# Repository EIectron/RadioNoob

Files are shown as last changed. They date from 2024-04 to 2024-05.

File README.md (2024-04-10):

<div align="center">
  <b>
   <h1>
      Radionoob AT9
   </h1>
   <h6>
     V1
   </h6>
  </b>

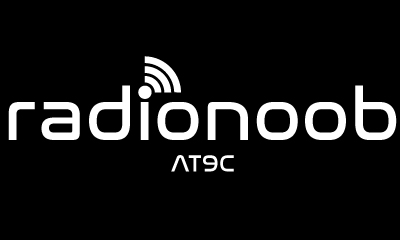
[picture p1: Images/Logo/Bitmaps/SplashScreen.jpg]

</div>

## What is this project?
My aim in this project, which I started as a hobby using the box of my broken Radiolink AT9 radio transmitter, was to control the drone in a simple way using the [ExpressLRS](https://github.com/ExpressLRS) module. In addition, I designed equipment that will contribute to my personal development. 
[For hardware information](Hardware.md);

I have personally reached the end of this project that I created with these goals. Even though it is not completely professional, I have created a remote control that will do the job. I made both the hardware and software files open source to guide beginners who want to make their own remote control. Who knows, maybe someone will make the code I wrote more meaningful :)

### This short demonstration [Youtube](https://youtu.be/xDq1djXwKw4)

## Known bugs;
- [ ] DAC player has been disabled because it falling CRSF communication.
- [ ] I cannot refresh much on the main screen, the delay is too much.
- [ ] There is an error in the screen refresh when moving to the upper menu on the ExpressLRS settings page.
- [ ] I never looked at the battery reading section.

### Goals for advanced level?
- [ ] The software must be converted to task structure with FreeRTOS.
- [ ] When I connect the USB, it should offer the option "charging or SIMULATOR" and continue according to my choice. An animation of the battery charging, maybe a current graph, and in the simulator, it goes into HID mode and communicates with the computer.

### Sources that inspired me while doing this project:
- [@danxdz](https://www.github.com/danxdz) https://github.com/danxdz/simpleTx_esp32/tree/master
- [@kkbin505](https://www.github.com/kkbin505) https://github.com/kkbin505/Arduino-Transmitter-for-ELRS
- [@DeviationTX](https://www.github.com/DeviationTX) https://github.com/DeviationTX/deviation
- [@r-u-t-r-A](https://www.github.com/r-u-t-r-A) https://github.com/r-u-t-r-A/STM32-ELRS-Handset/tree/4b6b6f61b5f094afb384d3d6aad8195b43e8a78a
- [@opentx](https://www.github.com/opentx) https://github.com/opentx/opentx/tree/2.3
- [@crsf-wg](https://www.github.com/crsf-wg) https://github.com/crsf-wg/crsf
* https://caolan.uk/notes/2020-10-14_bramley_driving_a_sharp_memory_display_from_rust/

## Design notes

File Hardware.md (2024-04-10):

<div align="center">
  <b>
   <h1>
      Radionoob AT9
   </h1>
   <h6>
     V1
   </h6>
  </b>

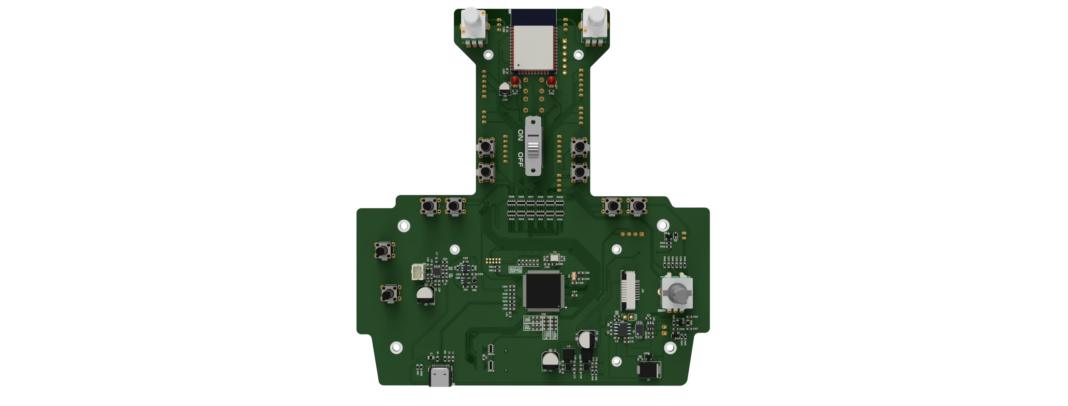
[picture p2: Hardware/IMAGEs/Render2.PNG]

</div>

#### Hardware Features;
* Nuvoton **M483KIDAE** MCU Arm® Cortex®-M4F processor 192 MHz
* 1S LiPo or 18650 Li-Ion Battery USB charge and protection
* 2.4GHz ELRS Transmitter W/ S.PORT
* PAM8304ASR DAC1 Audio sound output
* USB2.0 Full Speed communication
* SD Card
* 2.7" Sharp Memory Display
* 8x Trim button
* 8x Analog Input
* 5x One Way Button (SWA, SWB, SWD, SWF, SWH)
* 3x Two Way Button (SWCup, SWCdwn, SWEup, SWEdwn, SWGup, SWGdwn)
* PPM Data in & PPM Data out
* PWM vibration motor
* 12-bit 5 MSPS SAR ADC

### Check [Schematic](./Hardware/Schematic/RadioNoob.pdf)

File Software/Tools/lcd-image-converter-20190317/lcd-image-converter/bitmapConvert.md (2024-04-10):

## How to convert pictures for monochrome sharp memory display?

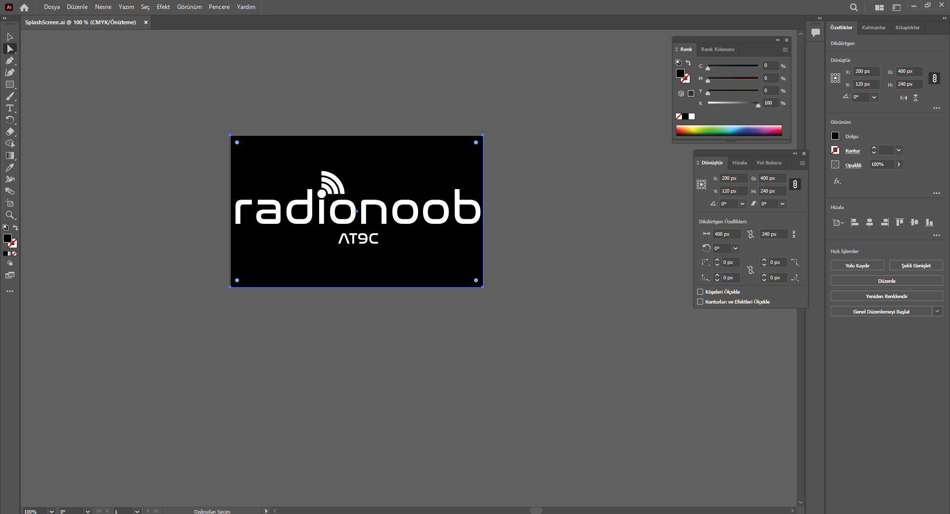
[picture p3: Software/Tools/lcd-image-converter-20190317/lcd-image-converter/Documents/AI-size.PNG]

1.) The dimensions of your work in the visual design program should not be larger than 400x240 pixels.

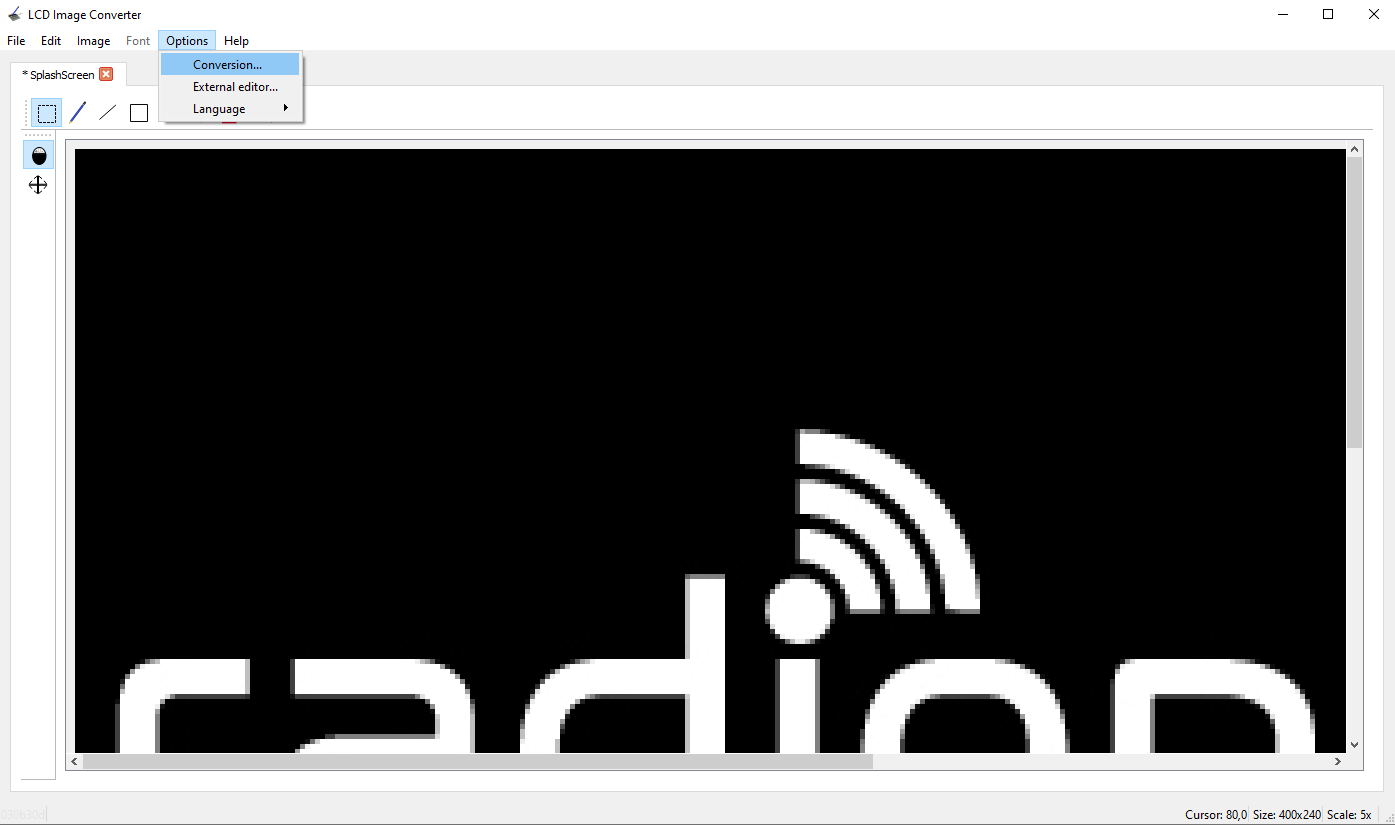
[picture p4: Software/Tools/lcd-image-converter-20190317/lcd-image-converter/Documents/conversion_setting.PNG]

2.) And open the image .jpeg or .png doesn't matter. Enter the conversions setting from the options tab

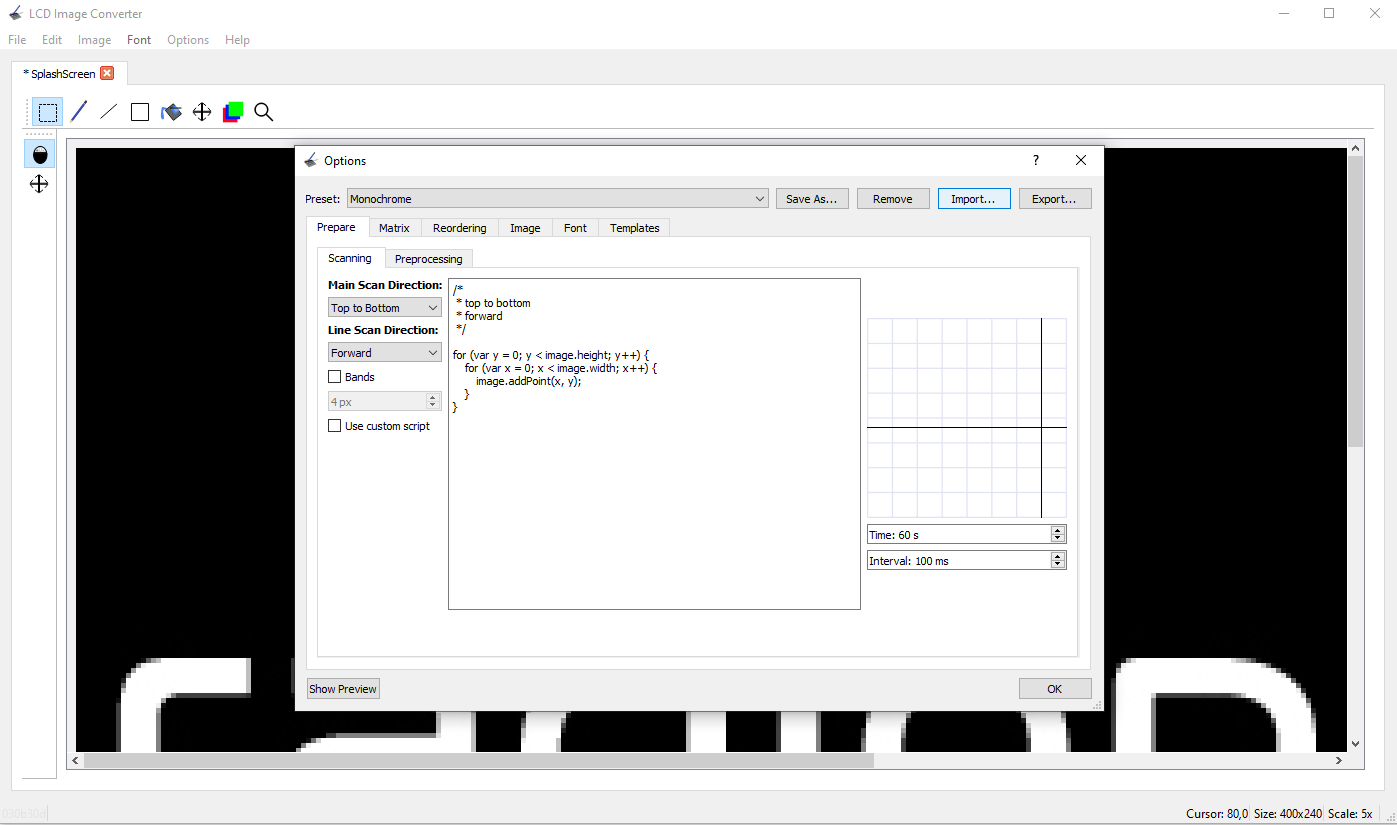
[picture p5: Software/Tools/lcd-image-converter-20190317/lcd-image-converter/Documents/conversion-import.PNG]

3. Import to Monochrome.xml file.

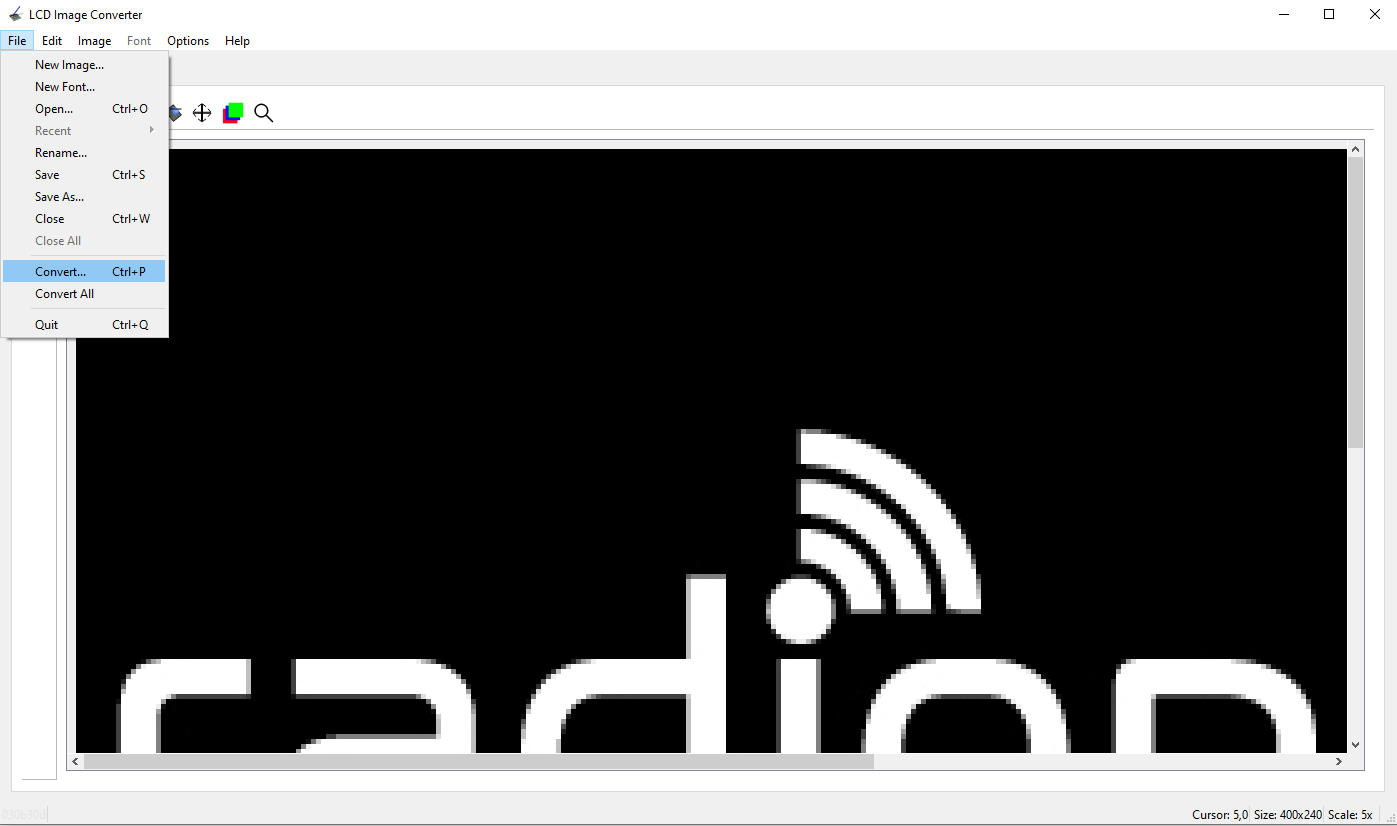
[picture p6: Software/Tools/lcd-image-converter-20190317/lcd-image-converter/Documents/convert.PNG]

4. Convert image

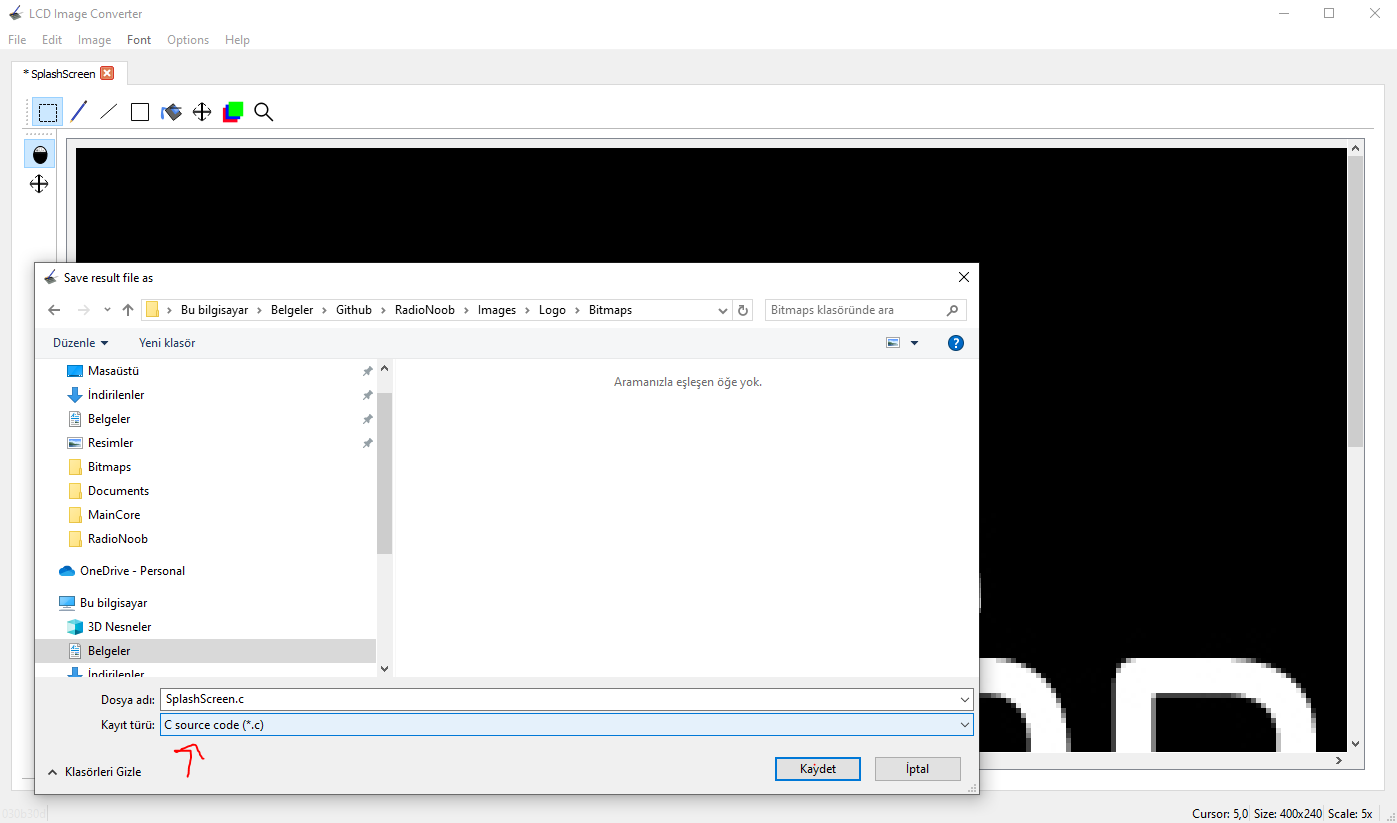
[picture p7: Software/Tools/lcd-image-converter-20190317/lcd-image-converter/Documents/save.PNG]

5. File settings must be `C source code(*.c)`

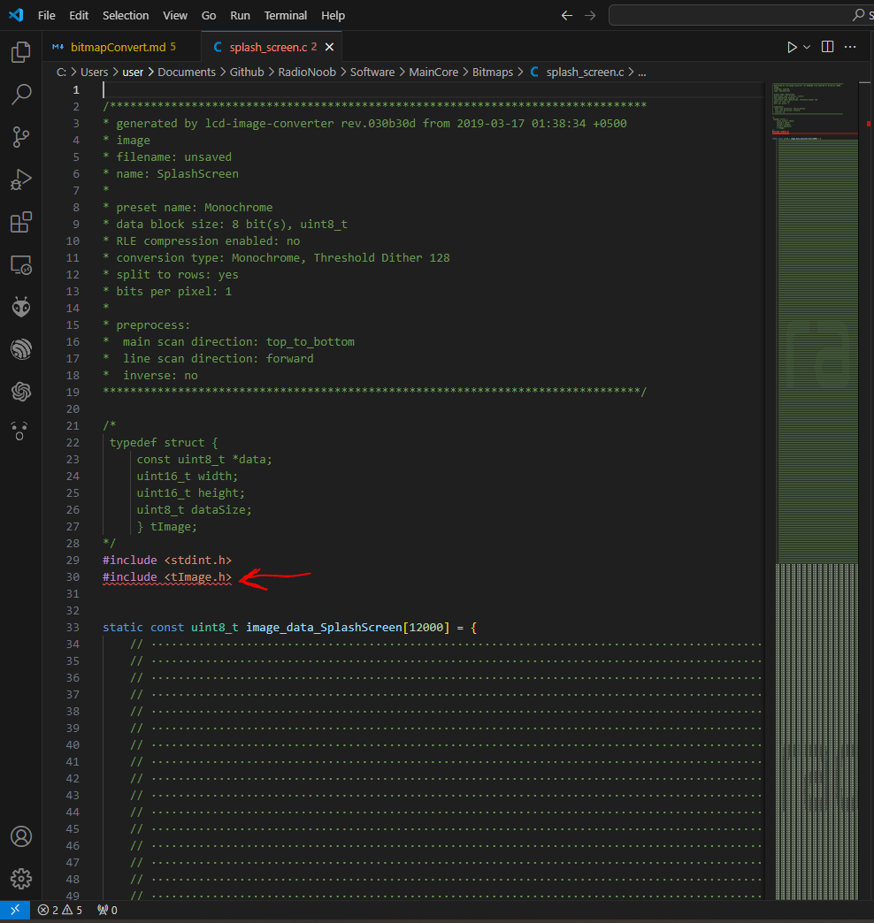
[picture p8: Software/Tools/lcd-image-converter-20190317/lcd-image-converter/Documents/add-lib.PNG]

6. After open the converted file and add to up side `#include <tImage.h>`

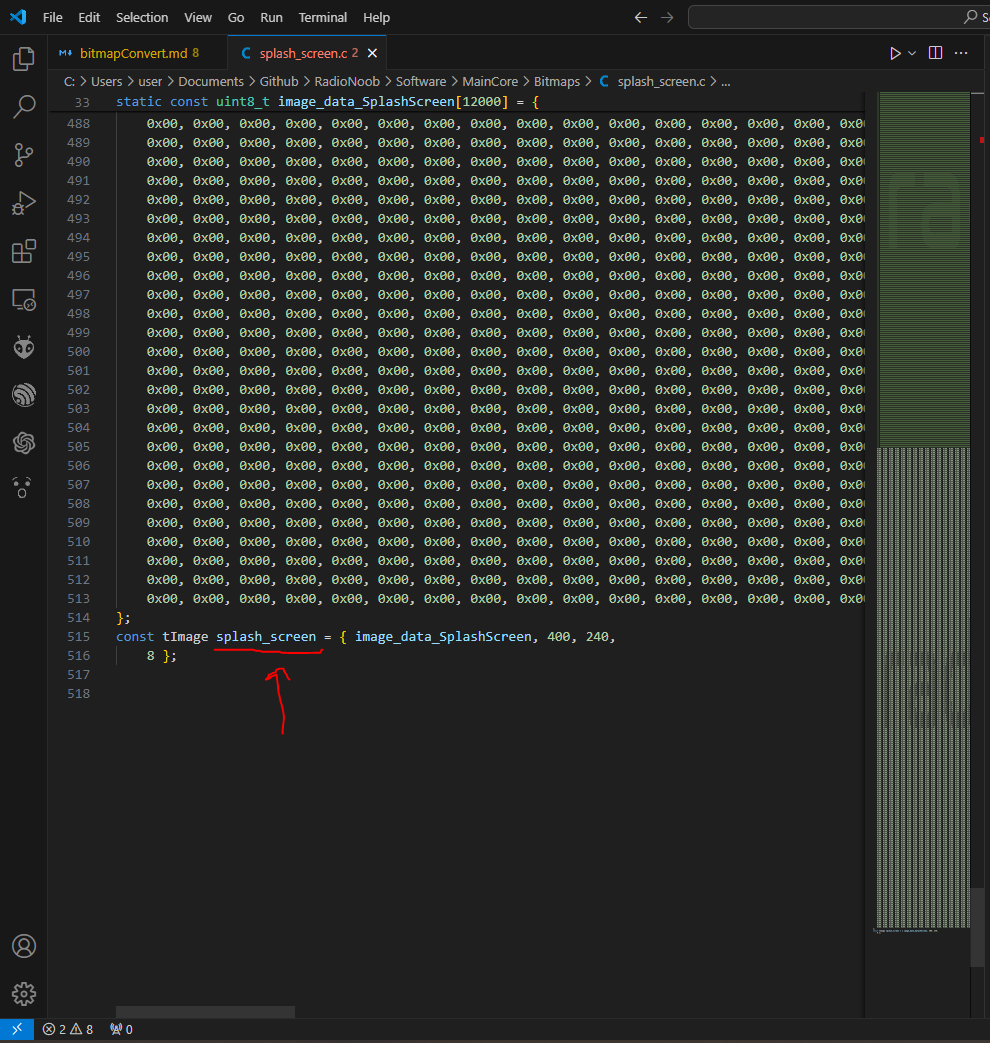
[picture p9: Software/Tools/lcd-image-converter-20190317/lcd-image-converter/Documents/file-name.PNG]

7. This is c file name

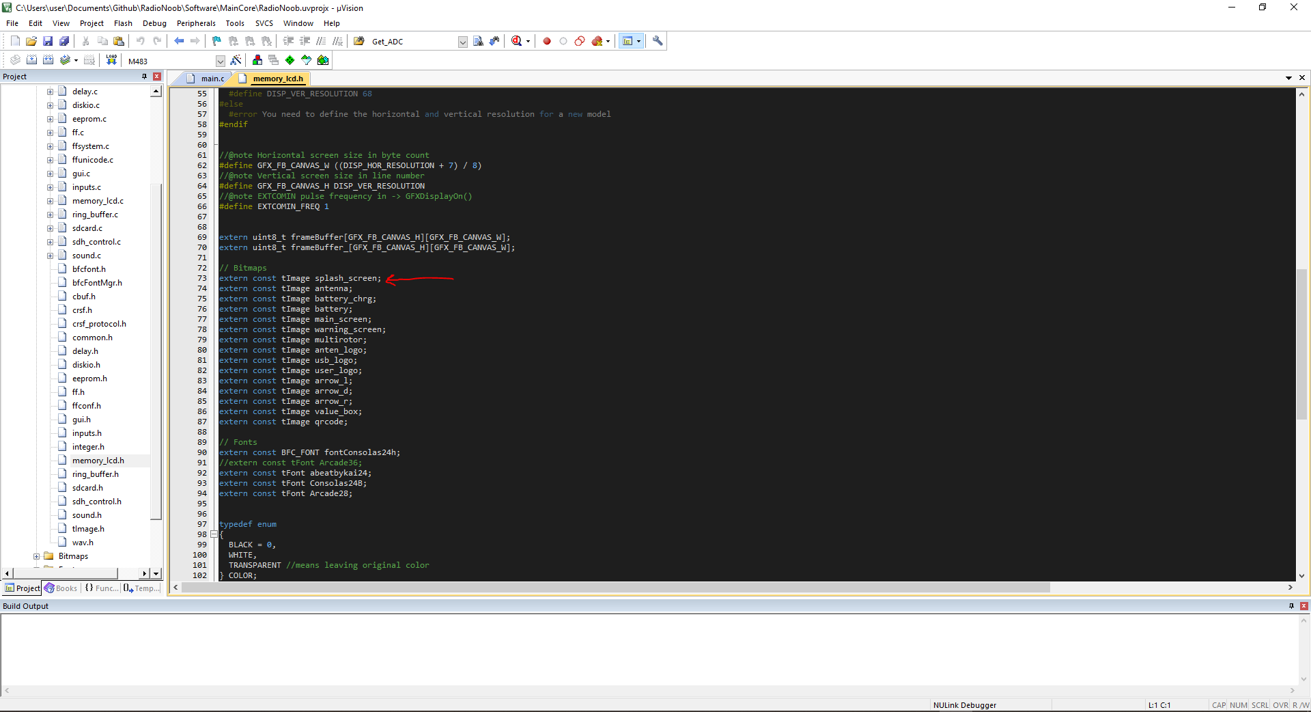
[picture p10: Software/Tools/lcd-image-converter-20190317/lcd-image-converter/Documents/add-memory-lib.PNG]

8. It is ready for use after adding it to the memory_lcd.h file in the Library folder as shown in the figure.

ex. 
``` C
GFXDisplayPutImage(0, 0, &splash_screen, false);
```

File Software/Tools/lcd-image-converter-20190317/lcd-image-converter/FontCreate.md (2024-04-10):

## How to convert pictures for monochrome sharp memory display?

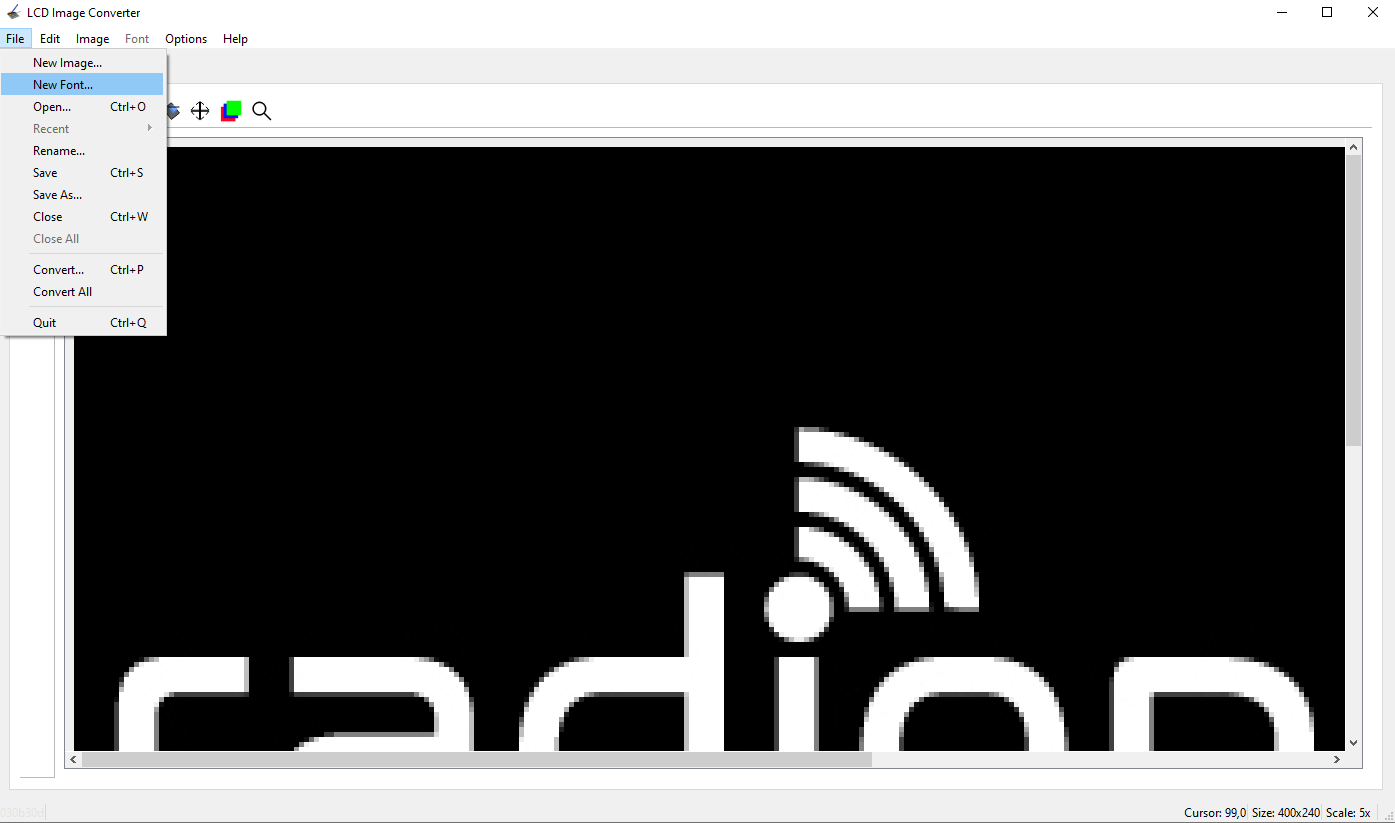
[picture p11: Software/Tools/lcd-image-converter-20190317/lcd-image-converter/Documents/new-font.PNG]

1. First, open a word file and check whether the font you want to create is installed on your computer. The font sizes of the font you choose are important. Because you need to know this in order to be standard when giving a name. For example, the naming for an arial font of size 14 will be "Arial14". If I name it "Arial22", if there is no such size, I will have to create it again. If all checks ok you click to File -> New Font and Write to your selected Font Name.

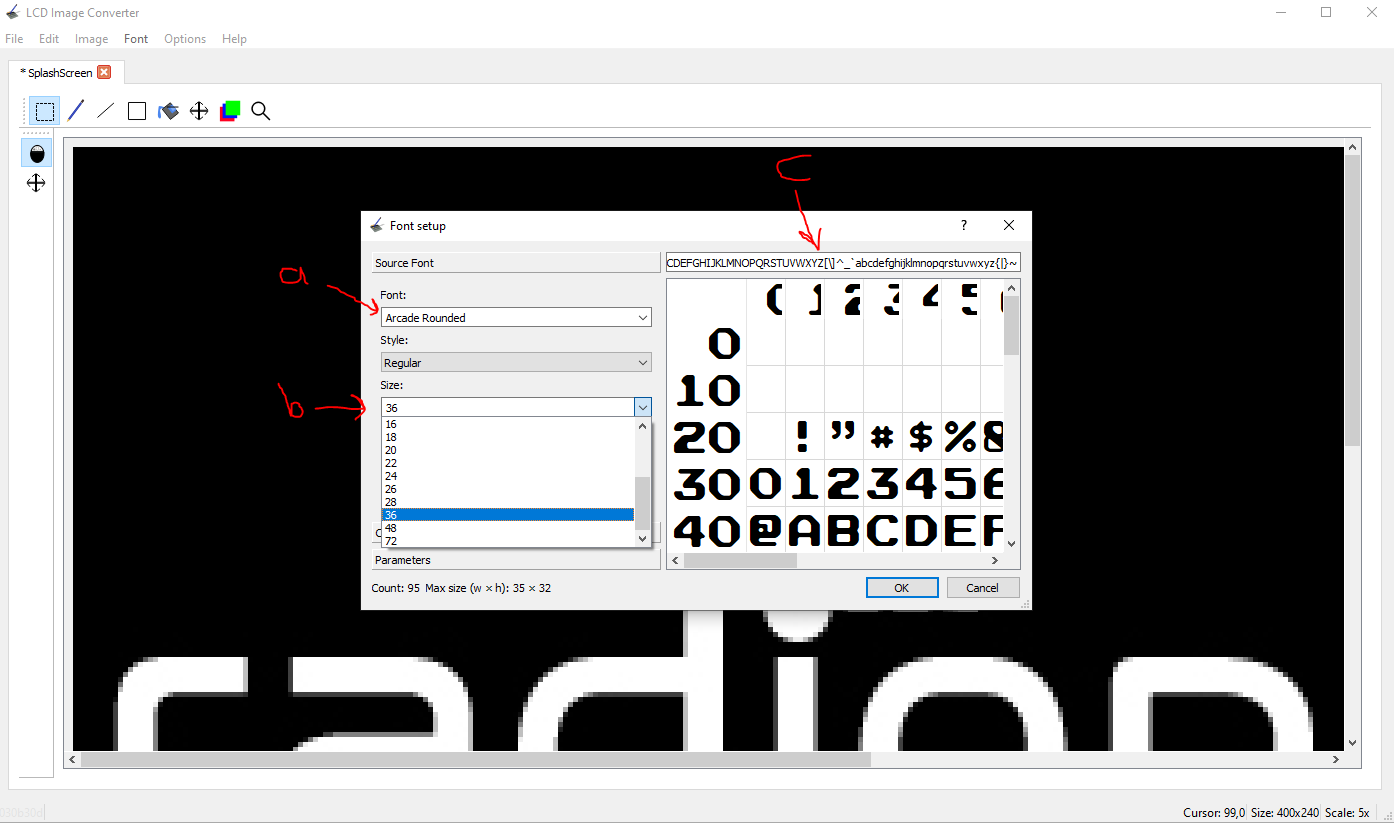
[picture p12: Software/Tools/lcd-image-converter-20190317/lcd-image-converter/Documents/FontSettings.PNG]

2. 
* a Select font
* b Select font size
* c delete unused characters. It would be nice if unused characters are deleted as they will take up less space in memory.

and save

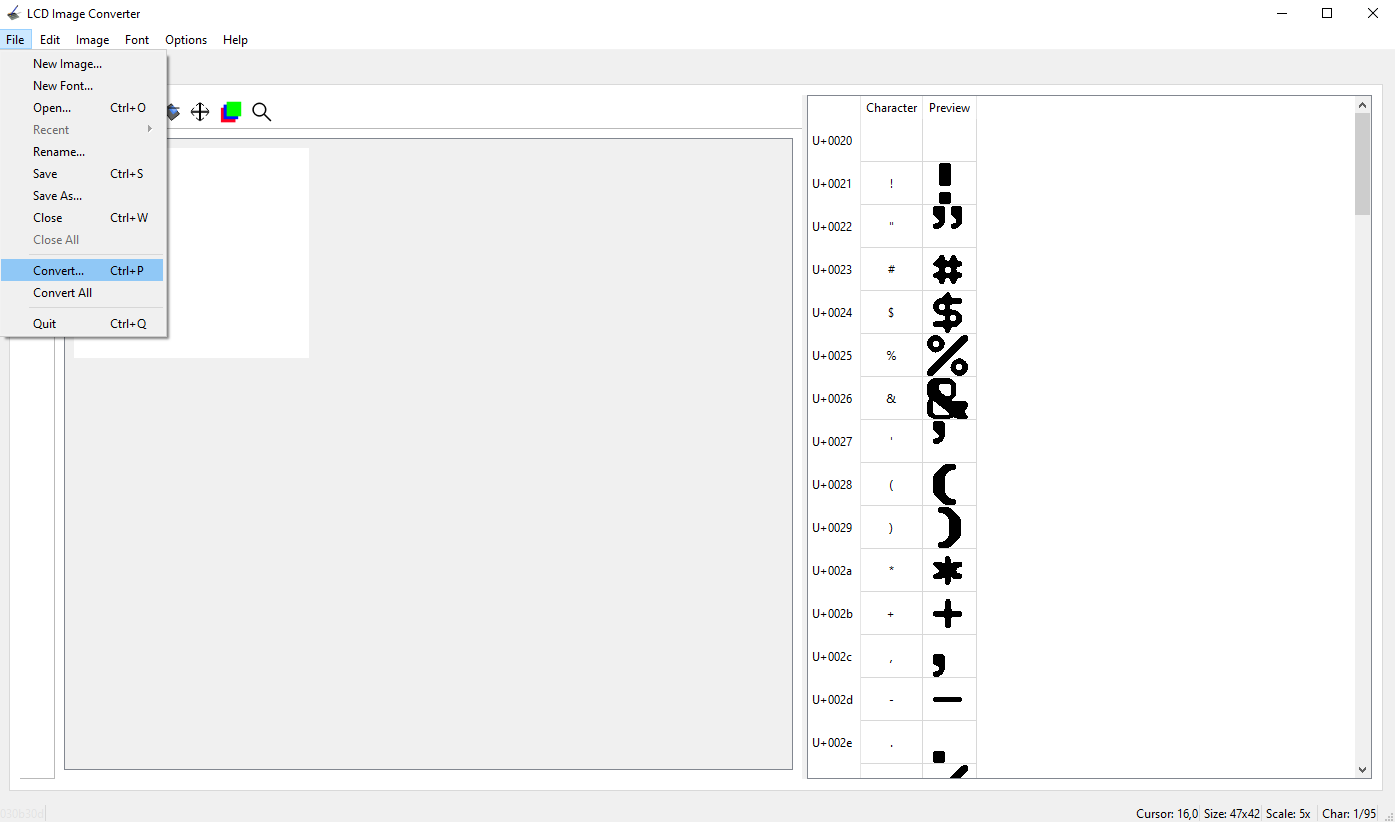
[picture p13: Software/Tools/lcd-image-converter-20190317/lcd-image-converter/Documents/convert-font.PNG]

3. File -> Convert. Conversion options must be selected monochrome preset. [eg;](./bitmapConvert.md)

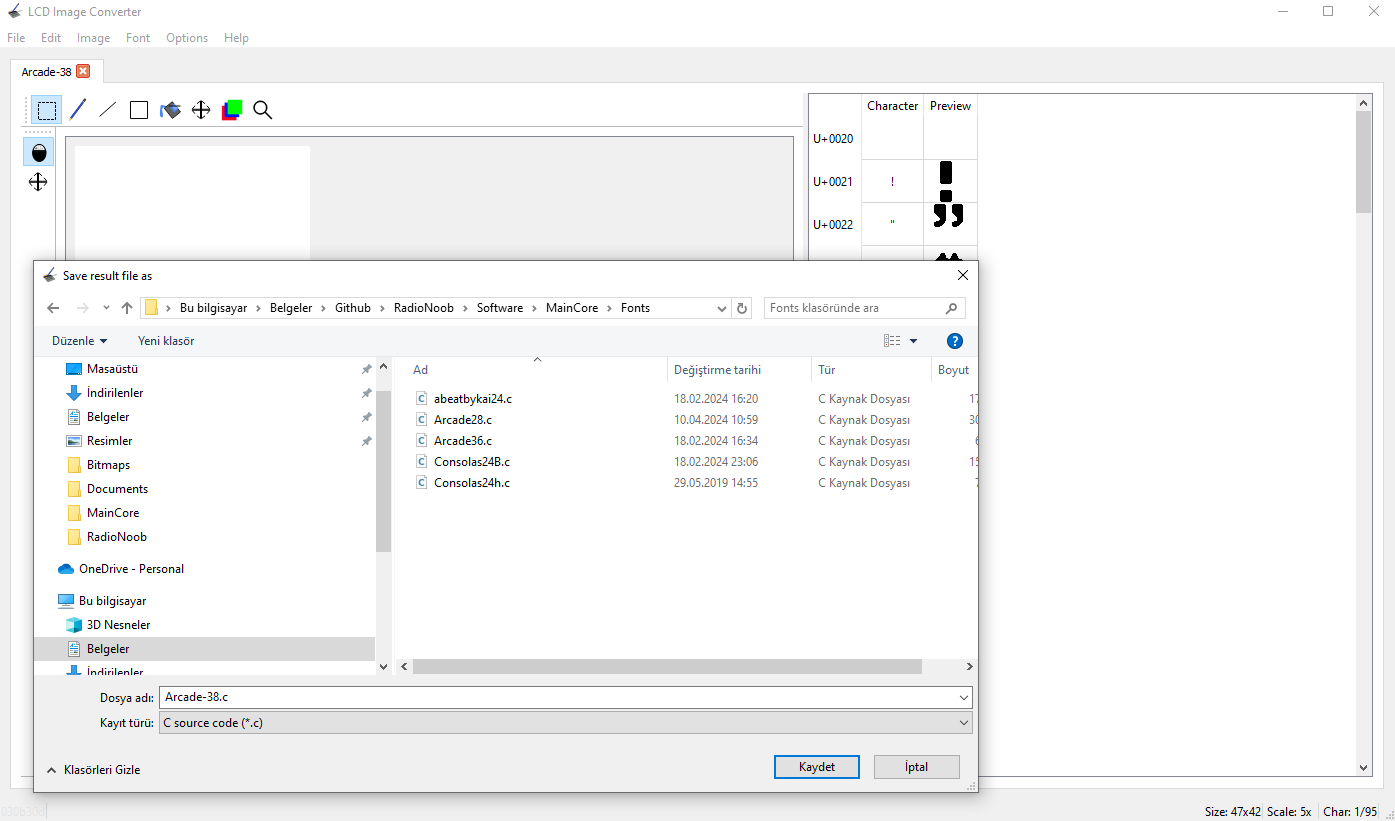
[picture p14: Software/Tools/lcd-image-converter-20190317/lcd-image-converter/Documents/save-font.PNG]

4. Save to font your font direction. File type must be selected `C source code (*.c)`

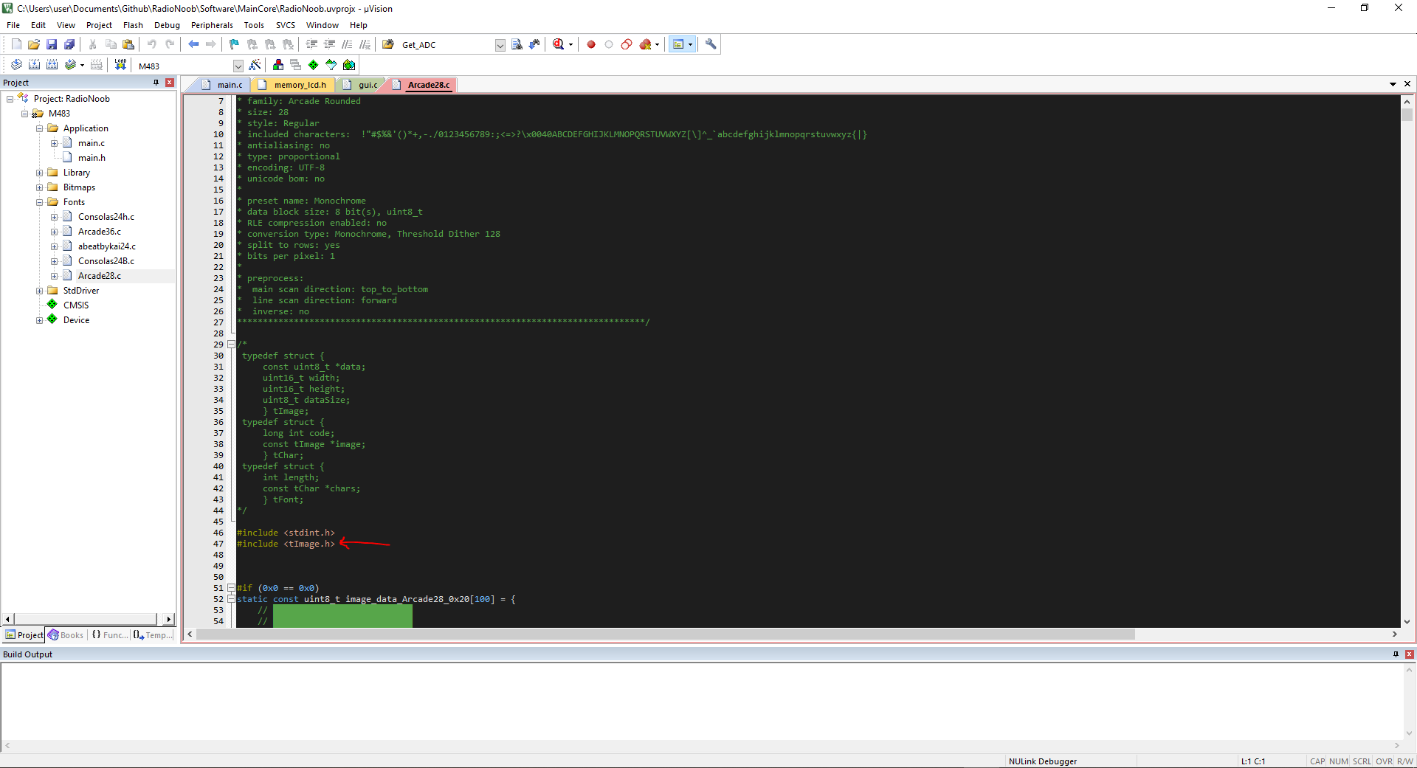
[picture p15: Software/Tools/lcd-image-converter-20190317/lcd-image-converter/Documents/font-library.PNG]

5. Add to upside `#include <tImage.h>` library header file

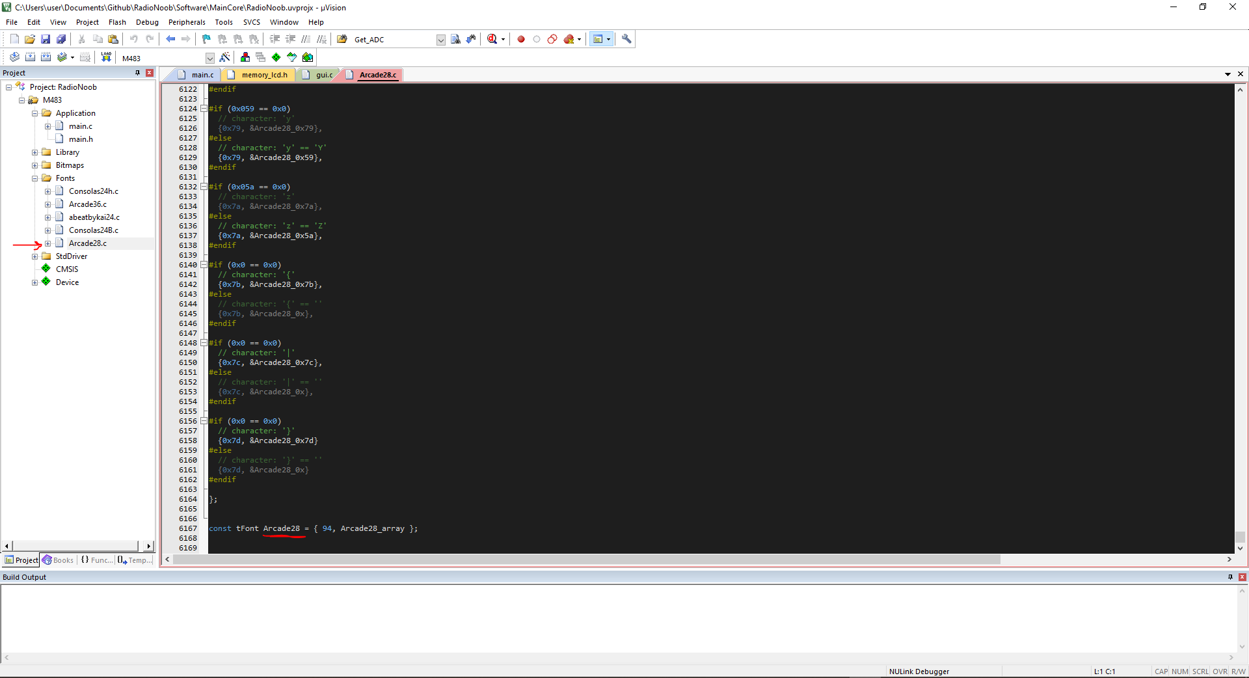
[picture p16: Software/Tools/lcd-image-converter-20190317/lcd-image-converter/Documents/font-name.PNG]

6. This is font name

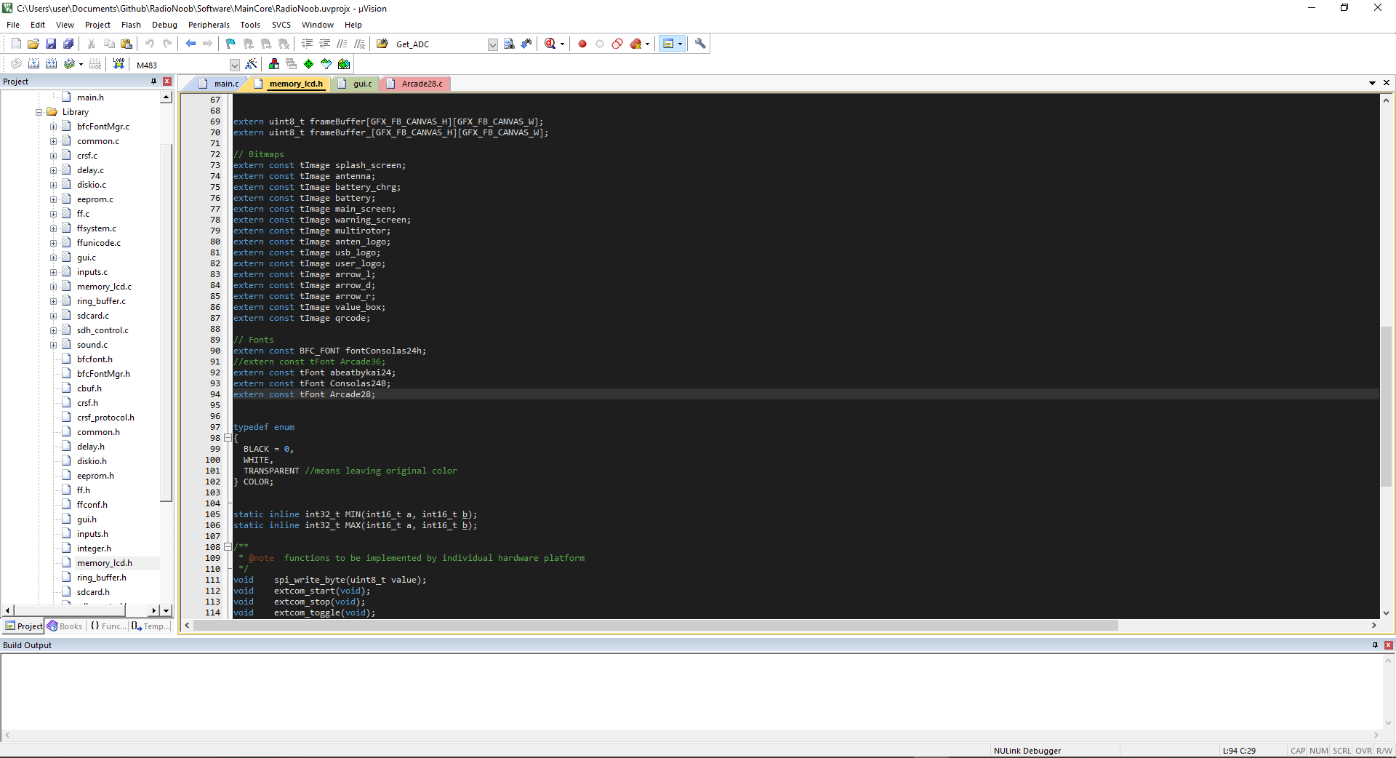
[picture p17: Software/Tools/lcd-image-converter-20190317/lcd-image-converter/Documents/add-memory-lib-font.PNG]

7. Add to library memory_lcd.h file.

eg;
```C
GFXDisplayPutText(25, 50, &Arcade28, "00:00", BLACK);	
```

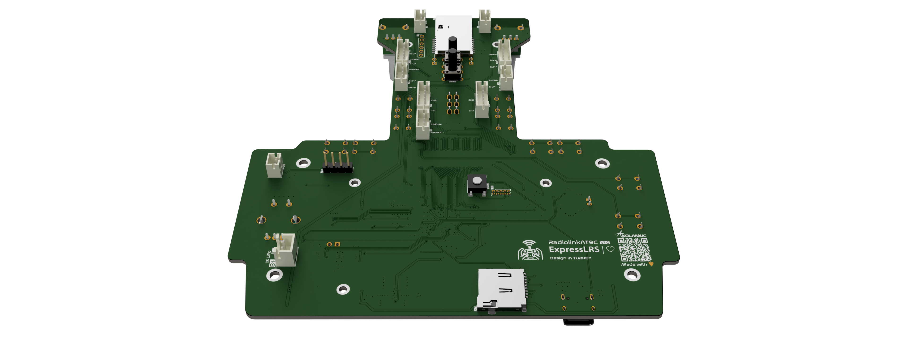
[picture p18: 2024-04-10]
Hardware/IMAGEs/Render1.PNG

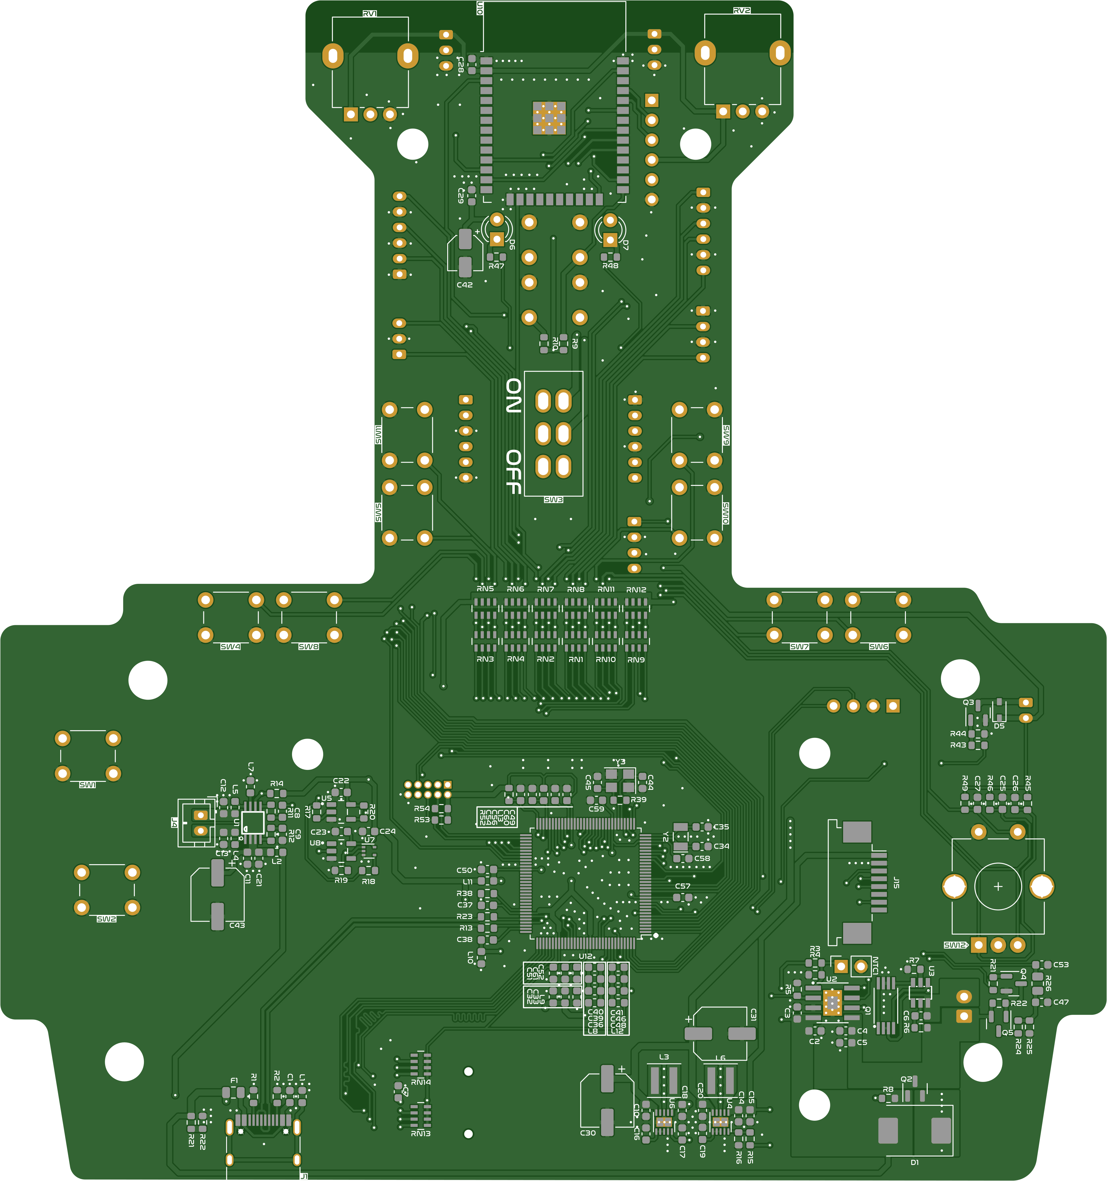
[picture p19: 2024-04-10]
Hardware/IMAGEs/RadioNoob/bottom.png

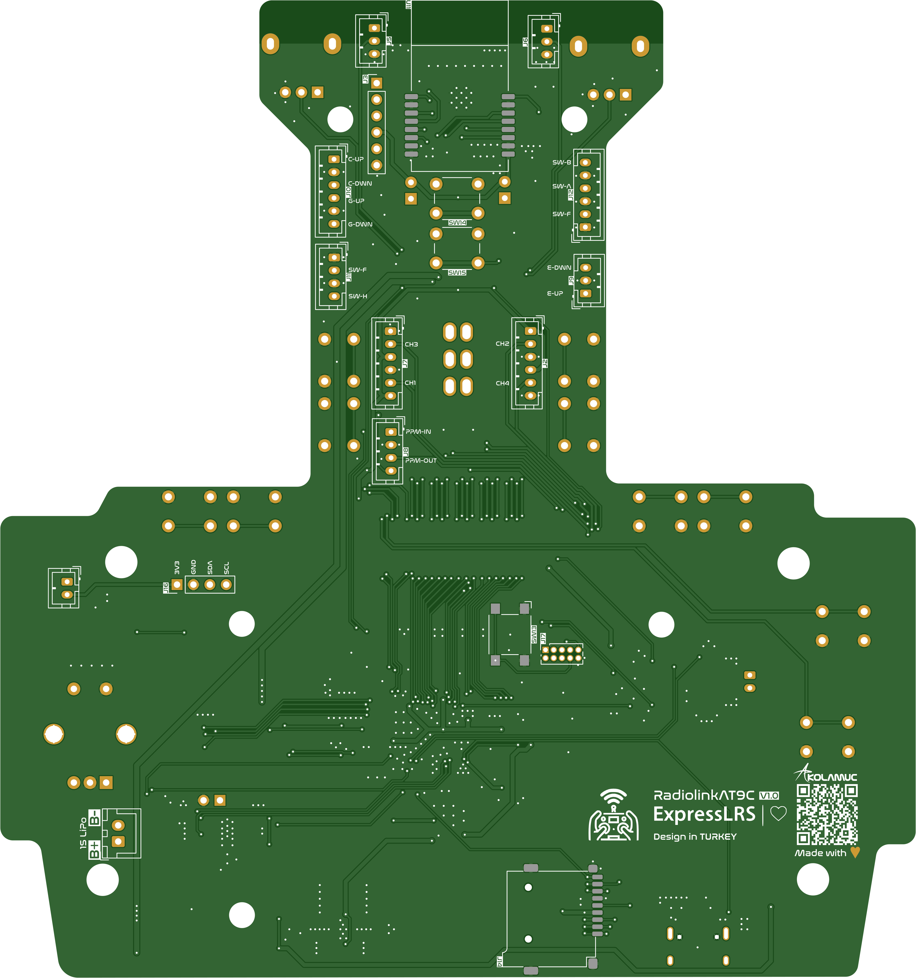
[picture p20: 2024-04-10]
Hardware/IMAGEs/RadioNoob/top.png

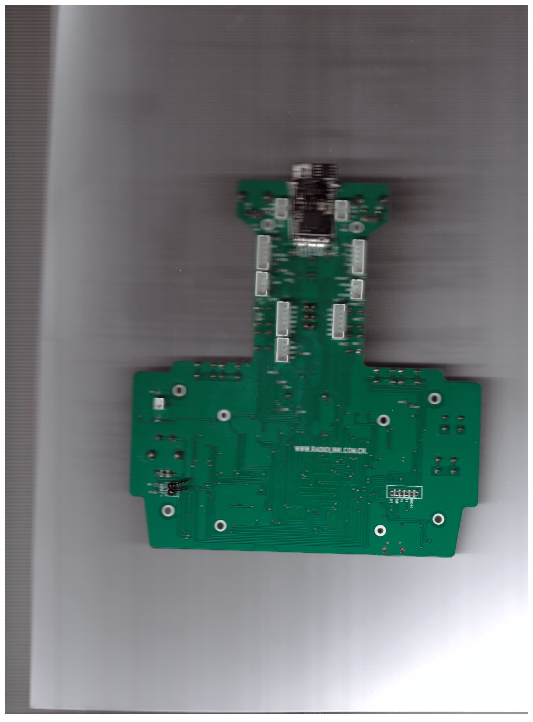
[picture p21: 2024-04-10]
Hardware/CADs/bot.jpeg

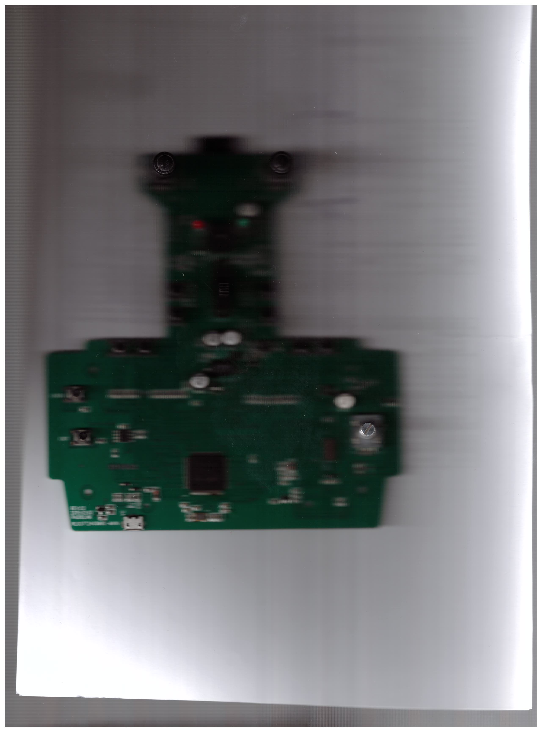
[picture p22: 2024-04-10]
Hardware/CADs/top.jpeg

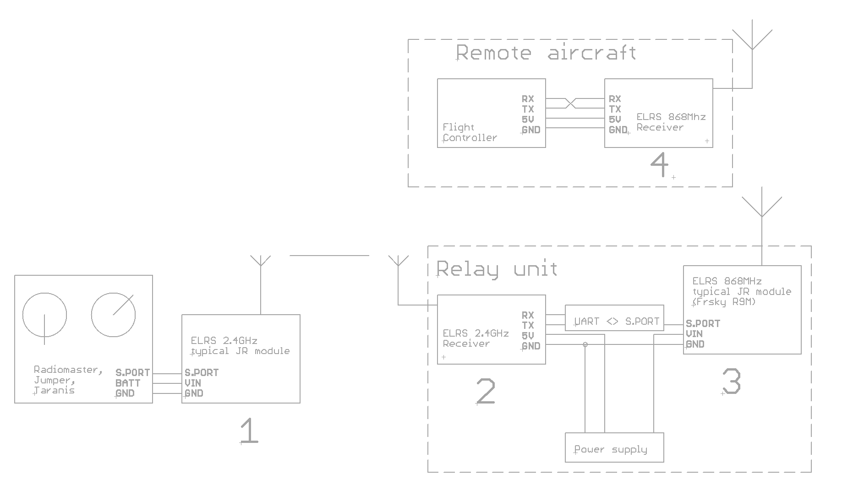
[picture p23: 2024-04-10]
Hardware/Documents/236402722-bd5ef522-5bf1-4fc4-926b-12082eae473d.png

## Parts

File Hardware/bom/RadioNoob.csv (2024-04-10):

Ref | Pieces | Device | Value | Package | Description | Suplier | Suplier Part Number | URL | Total Pieces | Birim USD | Maaliyet
BT1 | 1 | Battery_Cell | Battery_Cell | 1 | 1 | 1 | 1 | =KÖPRÜ("1")
C1, C11, C38, C40, C46, C54, C60, C61 | 8 | Capacitor | 1uF | 0603 | MLCC (1608) 0603 1uF 16VDC Â±10% X7R | Ozdisan | CL10B105KO8NNNC | =KÖPRÜ("https://ozdisan.com/Product/Detail/14234/CL10B105KO8NNNC")
C2, C4, C10, C14, C15, C20, C32 | 7 | Capacitor | 10uF | 0603 | MLCC (1608) 0603 10uF 6.3VDC Â±10% X5R | Ozdisan | CL10A106KP8NNNC | =KÖPRÜ("https://ozdisan.com/passive-components/capacitors/smt-smd-and-mlcc-capacitors/CL10A106KQ8NNNC")
C3, C5, C6, C7, C8, C9, C16, C17, C18, C19, C22, C23, C24, C25, C26, C27, C28, C29, C33, C37, C39, C49, C50, C51, C52, C56, C57, C58, C59 | 29 | Capacitor | 0.1uF | 0603 | MLCC (1608) 0603 100nF 50VDC Â±10% X7R | Ozdisan | CL10B104KB8NNNC | =KÖPRÜ("https://ozdisan.com/Product/Detail/9739/CL10B104KB8NNNC")
C12, C13 | 2 | Capacitor | 220pF | 0603 | MLCC (1608) 0603 220pF 50VDC Â±5% X7R | Ozdisan | CL10B221JB8NNNC | =KÖPRÜ("https://ozdisan.com/pasif-komponentler/kondansatorler/smt-smd-ve-mlcc-kondansatorler/CL10B221JB8NNNC/14795")
C21 | 1 | Capacitor | 100uF | 1210 | MLCC (3225) 1210 100uF 6.3VDC Â±20% X5R | Ozdisan | CL10A106KP8NNNC | =KÖPRÜ("https://ozdisan.com/pasif-komponentler/kapasitorler/smt-smd-ve-mlcc-kapasitorler/CL32A107MQVNNNE/359758")
C30, C31, C43 | 3 | Capacitor Polarized | 100uF | 6.3x5.4 | CAP.EL.100uF 16V 6.3x5.4 85C %20 SMD | Ozdisan | JCS1C101M063054 | =KÖPRÜ("https://ozdisan.com/pasif-komponentler/kapasitorler/aluminyum-kapasitorler/JCS1C101M063054/644947")
C34, C35, C44, C45 | 4 | Capacitor | 20pF | 0603 | MLCC (1608) 0603 20pF 50VDC Â±5% C0G (NP0) | Ozdisan | CL10C200JB8NNNC | =KÖPRÜ("https://ozdisan.com/pasif-komponentler/kondansatorler/smt-smd-ve-mlcc-kondansatorler/CL10C200JB8NNNC")
C36, C47, C53 | 3 | Capacitor | 0.01uF | 0603 | MLCC (1608) 0603 10nF 50VDC Â±10% X7R | Ozdisan | CL10B103KB8NNNC | =KÖPRÜ("https://ozdisan.com/passive-components/capacitors/smt-smd-and-mlcc-capacitors/CL10B103KB8NNNC")
C41 | 1 | Capacitor | 470pF | 0603 | MLCC (1608) 0603 470pF 50VDC Â±5% C0G (NP0) | Ozdisan | CL10C471JB8NNNC | =KÖPRÜ("https://ozdisan.com/passive-components/capacitors/smt-smd-and-mlcc-capacitors/CL10C471JB8NNNC")
C42 | 1 | Capacitor Polarized | 10uF | 4X5.4 | CAP.EL.10uF 35V 4X5.4 85C %20 SMT | Ozdisan | JCS1V100M040054 | =KÖPRÜ("https://ozdisan.com/pasif-komponentler/kapasitorler/aluminyum-kapasitorler/JCS1V100M040054/535049")
C48 | 1 | Capacitor | 2.2uF | 0603 | MLCC (1608) 0603 2.2uF 10VDC Â±10% X5R | Ozdisan | CL10A225KP8NNNC | =KÖPRÜ("https://ozdisan.com/passive-components/capacitors/smt-smd-and-mlcc-capacitors/CL10A225KP8NNNC")
D1 | 1 | D_Schottky | SS34 | DO-214AB SMC | DIODE SCHOTTKY 3A 40V DO-214AB SMC | Ozdisan | SS34C-MD | =KÖPRÜ("https://ozdisan.com/guc-yari-iletkenleri/diyotlar-modul-diyotlar-ve-dogrultucular/schottky-diyotlar/SS34C-MD/961961")
D5 | 1 | LL4148 | 1N4148WS | SOD323 | DIODE FAST SWITCHING Single 150mA 100V SMT SOD323 | Ozdisan | 1N4148WS | =KÖPRÜ("https://ozdisan.com/Product/Detail/442466/1N4148WS")
D6 | 1 | LED | Green | THT | LED 3MM GREEN 20mcd 45Â° GREEN/DIFFUSED | Ozdisan | 3G4HD-G03 | =KÖPRÜ("https://ozdisan.com/led-ve-aydinlatma-cozumleri/led-komponentler/sinyal-ledler-renkli/3G4HD-G03/5971")
D7 | 1 | LED | Red | THT | LED 3MM RED 30mcd 35Â° RED/DIFFUSED | Ozdisan | 3R4HD-7-TB | =KÖPRÜ("https://ozdisan.com/led-ve-aydinlatma-cozumleri/led-komponentler/sinyal-ledler-renkli/3R4HD-7-TB/430190")
F1 | 1 | Polyfuse_Small | 6V/1.5A | 0805 | THERMISTOR PTC RESETTABLE FUSE 0805 1.5A 6V | Ã–zdisan | KLM2S150RY | =KÖPRÜ("https://ozdisan.com/Product/Detail/645221/KLM2S150RY")
J1 | 1 | USB_C_Receptacle_USB2.0 | DS1144-18-16FS8BNR0 | SMD | CONN.USB C TYPE 16PIN SMT R/A FEMALE | Ozdisan | DS1144-18-16FS8BNR0 | =KÖPRÜ("https://ozdisan.com/konnektor-ve-baglanti-elemanlari/usb-dvi-hdmi-konnektorler/usb-konnektorler/DS1144-18-16FS8BNR0/649946")
J2, J7 | 2 | Conn_01x06_Male | JOYSTICK_LEFT | 1 | 1 | 1 | 1 | =KÖPRÜ("1")
J4 | 1 | Conn_01x02_Male | Speaker | 1 | 1 | 1 | 1 | =KÖPRÜ("1")
J5 | 1 | Conn_01x03_Male | POT-L | 1 | 1 | 1 | 1 | =KÖPRÜ("1")
J6 | 1 | Conn_01x03_Male | POT-R | 1 | 1 | 1 | 1 | =KÖPRÜ("1")
J8 | 1 | Conn_01x04_Male | EXT_MODUL | 1 | 1 | 1 | 1 | =KÖPRÜ("1")
J9 | 1 | Conn_01x03_Male | SW_E | 1 | 1 | 1 | 1 | =KÖPRÜ("1")
J10 | 1 | Conn_01x06_Male | SW_C_G | 1 | 1 | 1 | 1 | =KÖPRÜ("1")
J11 | 1 | Conn_01x04_Male | SW_D_H | 1 | 1 | 1 | 1 | =KÖPRÜ("1")
J12 | 1 | Conn_01x06_Male | SW_F_A_B | 1 | 1 | 1 | 1 | =KÖPRÜ("1")
J13 | 1 | Conn_01x02_Male | VIBRATION | 1 | 1 | 1 | 1 | =KÖPRÜ("1")
J14 | 1 | Micro_SD_Card_Det1 | Micro_SD_Card_Det1 | SMT | CONNECTOR MICRO SD CARD SMD KLS | Ozdisan | L-KLS1-TF-003-H1.85-R | =KÖPRÜ("https://ozdisan.com/konnektor-ve-baglanti-elemanlari/hafiza-konnektorleri/pc-kart-soketleri/L-KLS1-TF-003-H1-85-R/466548")
J15 | 1 | Conn_01x08_Pin | FPC | SMT R/A | CONN.FPC 8PIN 1.00MM SMT R/A BOTTOM CONTACT | Ozdisan | 311B-08LAA-R | =KÖPRÜ("https://ozdisan.com/konnektor-ve-baglanti-elemanlari/ffc-ve-fpc-serisi-konnektorleri/ffc-ve-fpc-konnektorler/311B-08LAA-R/597582")
J17 | 1 | Conn_02x05_Odd_Even | ICE | THT | PIN HEADER 10PIN(2x5) 2.54mm THT V/T | Ozdisan | L-KLS1-207-2-10-S | =KÖPRÜ("https://ozdisan.com/konnektor-ve-baglanti-elemanlari/header-konnektorler/pin-headerlar/L-KLS1-207-2-10-S")
L1, L2, L4, L5, L7, L8, L9, L10, L11, L12, L13 | 11 | L_Small | 220R | 0603 | FERRITE BEAD 0603 220R 1.4A | Ozdisan | BLM18PG221SN1D | =KÖPRÜ("https://ozdisan.com/Product/Detail/484088/BLM18PG221SN1D")
L3, L6 | 2 | L_Small | 1.5uH | SMT | INDUCTOR FIXED 1.5uH 7.5A %20 23.6mOHM SMD AECQ2 | Ozdisan | XEL4020-152MEC | =KÖPRÜ("https://ozdisan.com/pasif-komponentler/induktorler/sabit-induktorler/XEL4020-152MEC/736631")
NTC1 | 1 | Thermistor_NTC | 10K | THT | THERMISTOR NTC 10K 1% LMEM | Ozdisan | LM03G-103F | =KÖPRÜ("https://ozdisan.com/devre-koruyucular/termistorler/ntc-termistorler/LM03G-103F/36468")
Q1 | 1 | FS8205A | FS8205A | TSSOP-8 | IC-8205 MOSFET DRIVER 20V 6A 1V TSSOP-8 | Ozdisan | FS8205A | =KÖPRÜ("https://ozdisan.com/Product/Detail/607139/FS8205A")
Q2 | 1 | IRLML6402 | PJA3441 | SOT23-3 | MOSFET DIS.3.1A 40V P-CH SOT23 ENHANCEMENT SMT | Ozdisan | PJA3441_R2_00001 | =KÖPRÜ("https://ozdisan.com/Product/Detail/515398/PJA3441R200001")
Q3 | 1 | BC547 | BC817 | SOT-23 | TRANSISTOR DIS.500mA 45V NPN SOT23 GEN. SMT | Ozdisan | BC817-40,215 | =KÖPRÜ("https://ozdisan.com/guc-yari-iletkenleri/transistorler/discrete-transistorler/BC817-40215/16410")
Q4 | 1 | MMBT3904 | MMBT3904 | SOT-23 | TRANSISTOR DIS.200mA 40V NPN SOT23 EPITAXIAL SMT | Ozdisan | MMBT3904-HT | =KÖPRÜ("https://ozdisan.com/Product/Detail/468189/MMBT3904-HT")
Q5 | 1 | IRLML6402 | IRLML6402 |  |  |  |  | =KÖPRÜ("")
R1, R2 | 2 | Resistor | 5.1K | 0603 | RES.(1608) 0603 5.1K Ohms 5% 1/10W-S 100PPM | Ozdisan | 0603SAJ0512T5E | =KÖPRÜ("https://ozdisan.com/pasif-komponentler/direncler/smt-smd-ve-cip-direncler/0603SAJ0512T5E")
R3 | 1 | Resistor | 3.2K | 0603 | RES.(1608) 0603 3.24K Ohms 1% 1/10W-S 100PPM | Ozdisan | 0603SAF3241T5E | =KÖPRÜ("https://ozdisan.com/pasif-komponentler/direncler/smt-smd-ve-cip-direncler/0603SAF3241T5E/505878")
R4, R9, R10, R45, R46, R49 | 6 | Resistor | 4.7K | 0603 | RES.(1608) 0603 4.7K Ohms 1% 1/10W AUTOMOTIV | Ozdisan | CQ03SAF4701T5E | =KÖPRÜ("https://ozdisan.com/Product/Detail/587953/CQ03SAF4701T5E")
R5 | 1 | Resistor | 1.2K | 0603 | RES.(1608) 0603 1.2K Ohms 5% 1/10W-S 100PPM | Ozdisan | 0603SAJ0122T5E | =KÖPRÜ("https://ozdisan.com/pasif-komponentler/direncler/smt-smd-ve-cip-direncler/0603SAJ0122T5E/336235")
R6 | 1 | Resistor | 100R | 0603 | RES.(1608) 0603 100 Ohms 1% 1/5W 100PPM | Ozdisan | HP03W5F1000T5E | =KÖPRÜ("https://ozdisan.com/Product/Detail/585143/HP03W5F1000T5E")
R7, R17, R21, R47, R48 | 5 | Resistor | 1K | 0603 | RES.(1608) 0603 1K Ohms 1% 1/10W-S 100PPM | Ozdisan | 0603SAF1001T5E | =KÖPRÜ("https://ozdisan.com/Product/Detail/341789/0603SAF1001T5E")
R8, R11, R12, R22, R24, R25, R53, R54 | 8 | Resistor | 100K | 0603 | RES.(1608) 0603 100K Ohms 5% 1/10W-S 100PPM | Ozdisan | 0603SAJ0104T5E | =KÖPRÜ("https://ozdisan.com/pasif-komponentler/direncler/smt-smd-ve-cip-direncler/0603SAJ0104T5E/336252")
R13, R23 | 2 | Resistor | 33R | 0603 | RES.(1608) 0603 33 Ohms 1% 1/10W-S 200PPM | Ã–zdisan | 0603SAF330JT5E | =KÖPRÜ("https://ozdisan.com/pasif-komponentler/direncler/smt-smd-ve-cip-direncler/0603SAF330JT5E/342697")
R14, R19, R20, R44, R52 | 5 | Resistor | 10K | 0603 | RES.(1608) 0603 10K Ohms 1% 1/10W 25PPM | Ã–zdisan | TC0325F1002T5F | =KÖPRÜ("https://ozdisan.com/Product/Detail/727909/TC0325F1002T5F")
R15 | 1 | Resistor | 1.5MR | 0603 | RES.(1608) 0603 1.5M Ohms 1% 1/10W-S 100PPM | Ozdisan | 0603SAF1504T5E | =KÖPRÜ("https://ozdisan.com/pasif-komponentler/direncler/smt-smd-ve-cip-direncler/0603SAF1504T5E/516813")
R16 | 1 | Resistor | 165K | 0603 | RES.(1608) 0603 165K Ohms 1% 1/10W-S 100PPM | Ozdisan | 0603SAF1653T5E | =KÖPRÜ("https://ozdisan.com/pasif-komponentler/direncler/smt-smd-ve-cip-direncler/0603SAF1653T5E/430295")
R18 | 1 | Resistor | 51R | 0603 | RES.(1608) 0603 51 Ohms 1% 1/10W-S 200PPM | Ozdisan | 0603SAF510JT5E | =KÖPRÜ("https://ozdisan.com/pasif-komponentler/direncler/smt-smd-ve-cip-direncler/0603SAF510JT5E/343522")
R26 | 1 | R_Small_US | 51R | 0805 | RES.(2012) 0805 51 Ohms 5% 1/8W-S 200PPM | Ozdisan | 0805S8J0510T5E | =KÖPRÜ("https://ozdisan.com/pasif-komponentler/direncler/smt-smd-ve-cip-direncler/0805S8J0510T5E/349694")
R38 | 1 | Resistor | 200R | 0603 | RES.(1608) 0603 200 Ohms 1% 1/10W AUTOMOTIVE | Ozdisan | CQ03WAF2000T5E | =KÖPRÜ("https://ozdisan.com/pasif-komponentler/direncler/smt-smd-ve-cip-direncler/CQ03WAF2000T5E")
R39 | 1 | Resistor | 1MR | 0603 | RES.(1608) 0603 1M Ohms 1% 1/10W AUTOMOTIV | Ozdisan | CQ03SAF1004T5E | =KÖPRÜ("https://ozdisan.com/pasif-komponentler/direncler/smt-smd-ve-cip-direncler/CQ03SAF1004T5E")
R43 | 1 | Resistor | 220R | 0603 | RES.(1608) 0603 220 Ohms 1% 1/10W-S 100PPM | Ozdisan | 0603SAF2200T5E | =KÖPRÜ("https://ozdisan.com/Product/Detail/341792/0603SAF2200T5E")
RN1, RN2, RN3, RN4, RN9, RN10 | 6 | R_Pack04 | 220R | 4D03 | RES.NETWORK (4D03) 0603x4 220 Ohms 1% 1/16W SMT | Ozdisan | 4D03WGF2200T5E | =KÖPRÜ("https://ozdisan.com/pasif-komponentler/direncler/sira-direncler/4D03WGF2200T5E/423575")
RN5, RN6, RN7, RN8, RN11, RN12, RN13, RN14 | 8 | R_Pack04 | 10K | 4D03 | RES.NETWORK (4D03) 0603x4 10K Ohms 5% 1/16W SMT | Ozdisan | 4D03WGJ0103T5E | =KÖPRÜ("https://ozdisan.com/pasif-komponentler/direncler/sira-direncler/4D03WGJ0103T5E/32920")
RV1, RV2 | 2 | R_Potentiometer | R_Potentiometer | 1 | 1 | 1 | 1 | =KÖPRÜ("1")
SW1 | 1 | SW_MEC_5E | Mode | THT V/T | SWITCH TACT 6.00x6.00 7.00mm 260gF THT V/T | Ozdisan | DTS-63R-V | =KÖPRÜ("https://ozdisan.com/elektromekanik-komponentler/sivicler-ve-anahtarlar/tact-sivicler/DTS-63R-V/347479")
SW2 | 1 | SW_MEC_5E | End | THT V/T | SWITCH TACT 6.00x6.00 7.00mm 260gF THT V/T | Ozdisan | DTS-63R-V | =KÖPRÜ("https://ozdisan.com/elektromekanik-komponentler/sivicler-ve-anahtarlar/tact-sivicler/DTS-63R-V/347479")
SW3 | 1 | SW_Push_DPDT | ON/OFF | THT/VT | SWITCH SLIDE 2P2T 3A/500mA 125V/125V On-On THT V/T | Ozdisan | GF-126-0159 | =KÖPRÜ("https://ozdisan.com/elektromekanik-komponentler/sivicler-ve-anahtarlar/surgulu-sivicler/GF-126-0159/611526")
SW4 | 1 | SW_MEC_5E | Y- | THT V/T | SWITCH TACT 6.00x6.00 7.00mm 260gF THT V/T | Ozdisan | DTS-63R-V | =KÖPRÜ("https://ozdisan.com/elektromekanik-komponentler/sivicler-ve-anahtarlar/tact-sivicler/DTS-63R-V/347479")
SW5 | 1 | SW_MEC_5E | T- | THT V/T | SWITCH TACT 6.00x6.00 7.00mm 260gF THT V/T | Ozdisan | DTS-63R-V | =KÖPRÜ("https://ozdisan.com/elektromekanik-komponentler/sivicler-ve-anahtarlar/tact-sivicler/DTS-63R-V/347479")
SW6 | 1 | SW_MEC_5E | R+ | THT V/T | SWITCH TACT 6.00x6.00 7.00mm 260gF THT V/T | Ozdisan | DTS-63R-V | =KÖPRÜ("https://ozdisan.com/elektromekanik-komponentler/sivicler-ve-anahtarlar/tact-sivicler/DTS-63R-V/347479")
SW7 | 1 | SW_MEC_5E | R- | THT V/T | SWITCH TACT 6.00x6.00 7.00mm 260gF THT V/T | Ozdisan | DTS-63R-V | =KÖPRÜ("https://ozdisan.com/elektromekanik-komponentler/sivicler-ve-anahtarlar/tact-sivicler/DTS-63R-V/347479")
SW8 | 1 | SW_MEC_5E | Y+ | THT V/T | SWITCH TACT 6.00x6.00 7.00mm 260gF THT V/T | Ozdisan | DTS-63R-V | =KÖPRÜ("https://ozdisan.com/elektromekanik-komponentler/sivicler-ve-anahtarlar/tact-sivicler/DTS-63R-V/347479")
SW9 | 1 | SW_MEC_5E | P+ | THT V/T | SWITCH TACT 6.00x6.00 7.00mm 260gF THT V/T | Ozdisan | DTS-63R-V | =KÖPRÜ("https://ozdisan.com/elektromekanik-komponentler/sivicler-ve-anahtarlar/tact-sivicler/DTS-63R-V/347479")
SW10 | 1 | SW_MEC_5E | P- | THT V/T | SWITCH TACT 6.00x6.00 7.00mm 260gF THT V/T | Ozdisan | DTS-63R-V | =KÖPRÜ("https://ozdisan.com/elektromekanik-komponentler/sivicler-ve-anahtarlar/tact-sivicler/DTS-63R-V/347479")
SW11 | 1 | SW_MEC_5E | T+ | THT V/T | SWITCH TACT 6.00x6.00 7.00mm 260gF THT V/T | Ozdisan | DTS-63R-V | =KÖPRÜ("https://ozdisan.com/elektromekanik-komponentler/sivicler-ve-anahtarlar/tact-sivicler/DTS-63R-V/347479")
SW12 | 1 | RotaryEncoder_Switch | RotaryEncoder_Switch | THT | ENCODER 20MM EC11 15P 30C | Ozdisan | L-KLS4-EC1123S-E-5A-F20 | =KÖPRÜ("https://ozdisan.com/elektromekanik-komponentler/cevrilebilir-enkoderler/acisal-enkoderler/L-KLS4-EC1123S-E-5A-F20/513467")
SW13 | 1 | TACT_SW-4 | TACT_SW-4 | SMD | SWITCH TACT 6.20x6.20 2.50mm 160gF SMT V/T | Ozdisan | DS1042-07-1-1KRR16008 | =KÖPRÜ("https://ozdisan.com/elektromekanik-komponentler/sivicler-ve-anahtarlar/tact-sivicler/DS1042-07-1-1KRR16008")
SW14, SW15 | 2 | SW_MEC_5E | ELRS_IO | THT V/T | SWITCH TACT 6.00x6.00 7.00mm 260gF THT V/T | Ozdisan | DTS-63R-V | =KÖPRÜ("https://ozdisan.com/elektromekanik-komponentler/sivicler-ve-anahtarlar/tact-sivicler/DTS-63R-V/347479")
U1 | 1 | PAM8304ASR | PAM8304ASR | MSOP8 | IC-8304 AUDIO POWER AMPLIFIER 3W MONO MSOP-8L | Ozdisan | PAM8304ASR | =KÖPRÜ("https://ozdisan.com/entegre-devreler-ics/lineer-entegreler/amplifikatorler/PAM8304ASR/710784")
U2 | 1 | TP4056 | TP4056 | SOP8 | IC-4056 REG/STANDALONE LINEAR 1A SOP8 | Ozdisan | TP4056-42-SOP8-PP | =KÖPRÜ("https://ozdisan.com/Product/Detail/487879/TP4056-42-SOP8-PP")
U3 | 1 | DW01A | DW01A | SOT23-6 | IC-01 G BATTERY PROTECTION 1-CELL SOT23-6 FORTU | Ozdisan | DW01A | =KÖPRÜ("https://www.ozdisan.com/entegre-devreler-ics/guc-entegreleri/batarya-yonetimi-entegreleri/DW01A")
U4 | 1 | TPS63030DSK | TPS63030DSK | 10SON | IC-6303 REG BUCK BOOST ADJ 0.9A 10SON | Ozdisan | TPS63030DSKR | =KÖPRÜ("https://ozdisan.com/entegre-devreler-icler/guc-entegreleri/dc-dc-voltaj-regulatorleri/TPS63030DSKR/509319")
U5, U8 | 2 | SN74LVC1G04DBVR | SN74LVC1G04DBVR | SOT-23 | IC-74LVC1G04 SINGLE INVERTER GATE SOT23 | Ozdisan | SN74LVC1G04DBVR | =KÖPRÜ("https://ozdisan.com/entegre-devreler-icler/logic-entegreler/logic-kapi-ve-cevirici-entegreleri/SN74LVC1G04DBVR/609963")
U6 | 1 | TPS63031DSK | TPS63031DSK | VSON10 | High Efficiency Single Inductor Buck-Boost Converter | AE | TPS63031DSK | =KÖPRÜ("AE")
U7 | 1 | 74LVC1G126 | 74LVC1G126 | SOT-5 | IC-126 BUS BUFF TRI-ST N-INV SOT5 | Ozdisan | SN74LVC1G126DRLR | =KÖPRÜ("https://ozdisan.com/entegre-devreler-icler/logic-entegreler/buffer-driver-receiver-ve-transceiver-entegreleri/SN74LVC1G126DRLR/515961")
U10 | 1 | ESP32-WROOM-32D | ESP32-WROOM-32D | MODULE / 18 x 2.5 x 3.1 | MODULE WIFI BLUETOOTH 4MB DUALCORE | Ozdisan | ESP32-WROOM-32D | =KÖPRÜ("https://ozdisan.com/Product/Detail/584995/ESP32-WROOM-32D")
U11 | 1 | E28-2G4M27S | E28-2G4M27S | 1 | 1 | 1 | E28-2G4M27S | =KÖPRÜ("AE")
U12 | 1 | M483KIDAE | M483KIDAE | LQFP128 | MCU 32BIT ARM M4 512KB FLASH 160KB RAM LQFP128 | Ozdisan | M483KIDAE | =KÖPRÜ("https://ozdisan.com/Product/Detail/528715/M483KIDAE")
Y2 | 1 | Crystal | 32.768kHz | 2-SMD | CRYSTAL 32.768KHZ 6PF SMD | Ozdisan | ABS07-120-32.768KHZ-T | =KÖPRÜ("https://ozdisan.com/Product/Detail/446332/ABS07-120-32-768KHZ-T")
Y3 | 1 | Crystal_GND24_Small | 12MHz | 4-SMD | CRYSTAL 12MHZ 18pF 4-SMD | Ozdisan | RH100-12.000-18-2020-TR | =KÖPRÜ("https://ozdisan.com/pasif-komponentler/kristaller-osilatorler-ve-rezanatorler/kristaller/RH100-12-000-18-2020-TR")
Date: | 1.12.2023 19:45:27
Tool: | Eeschema 7.0.8
Component Count: | 182

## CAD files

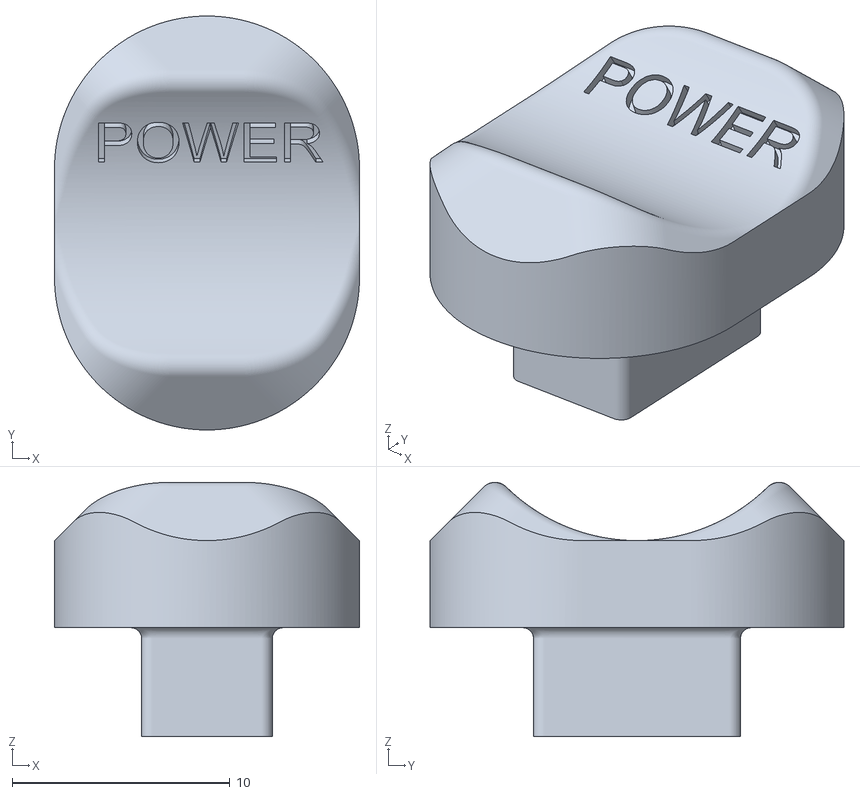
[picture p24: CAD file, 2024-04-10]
CAD/PowerSlideKnob.stl
14.0 x 19.0 x 11.7

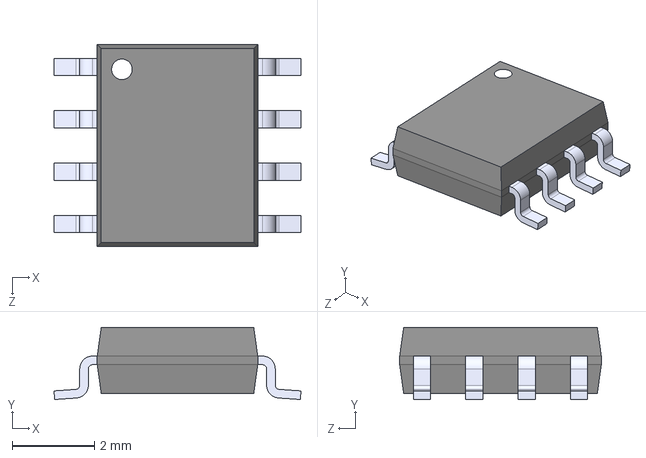
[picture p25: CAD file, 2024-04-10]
Hardware/3D/TP4056.step
6.00 x 1.75 x 4.90 mm

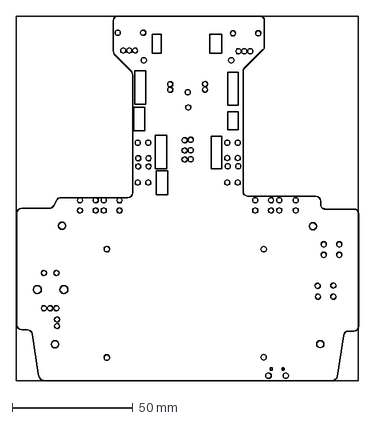
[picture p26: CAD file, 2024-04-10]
Hardware/CADs/RadiolinkAT9-PCB.dxf
142.0 x 151.3 mm

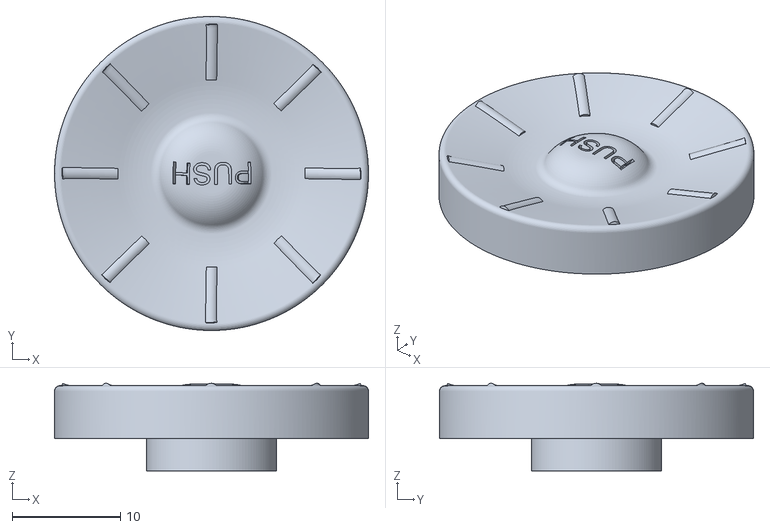
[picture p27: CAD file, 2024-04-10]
CAD/RotaryKnob.stl
29.0 x 29.0 x 8.08

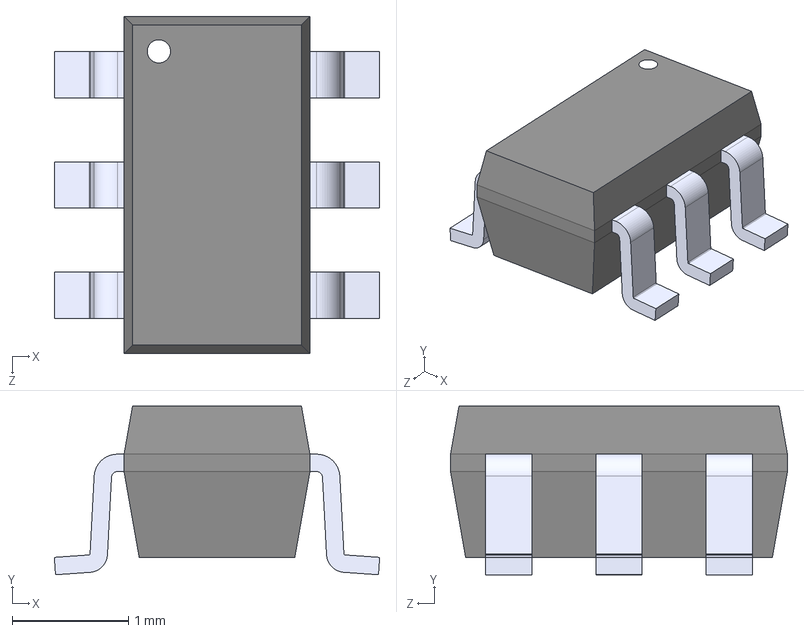
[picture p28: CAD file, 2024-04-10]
Hardware/3D/DW01A.step
2.80 x 1.45 x 2.90 mm

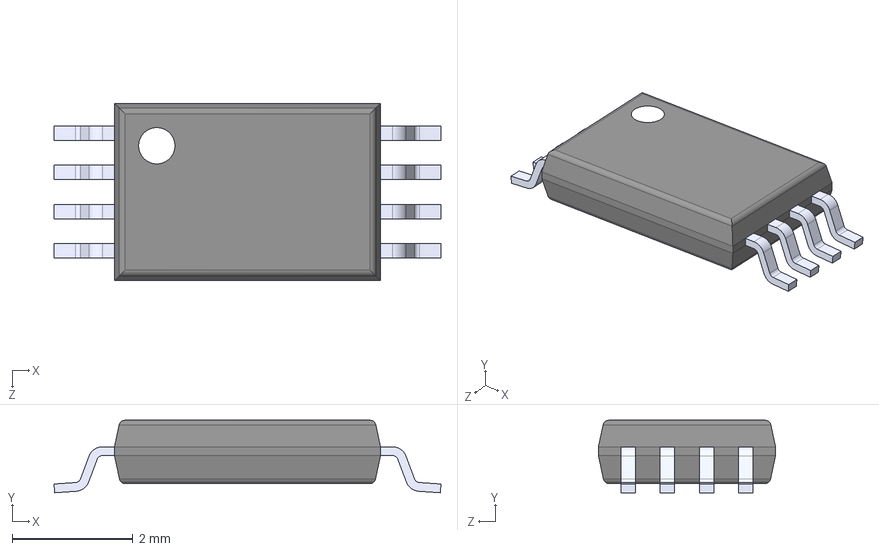
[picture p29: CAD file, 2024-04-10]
Hardware/3D/FS8205A.step
6.40 x 1.20 x 2.93 mm

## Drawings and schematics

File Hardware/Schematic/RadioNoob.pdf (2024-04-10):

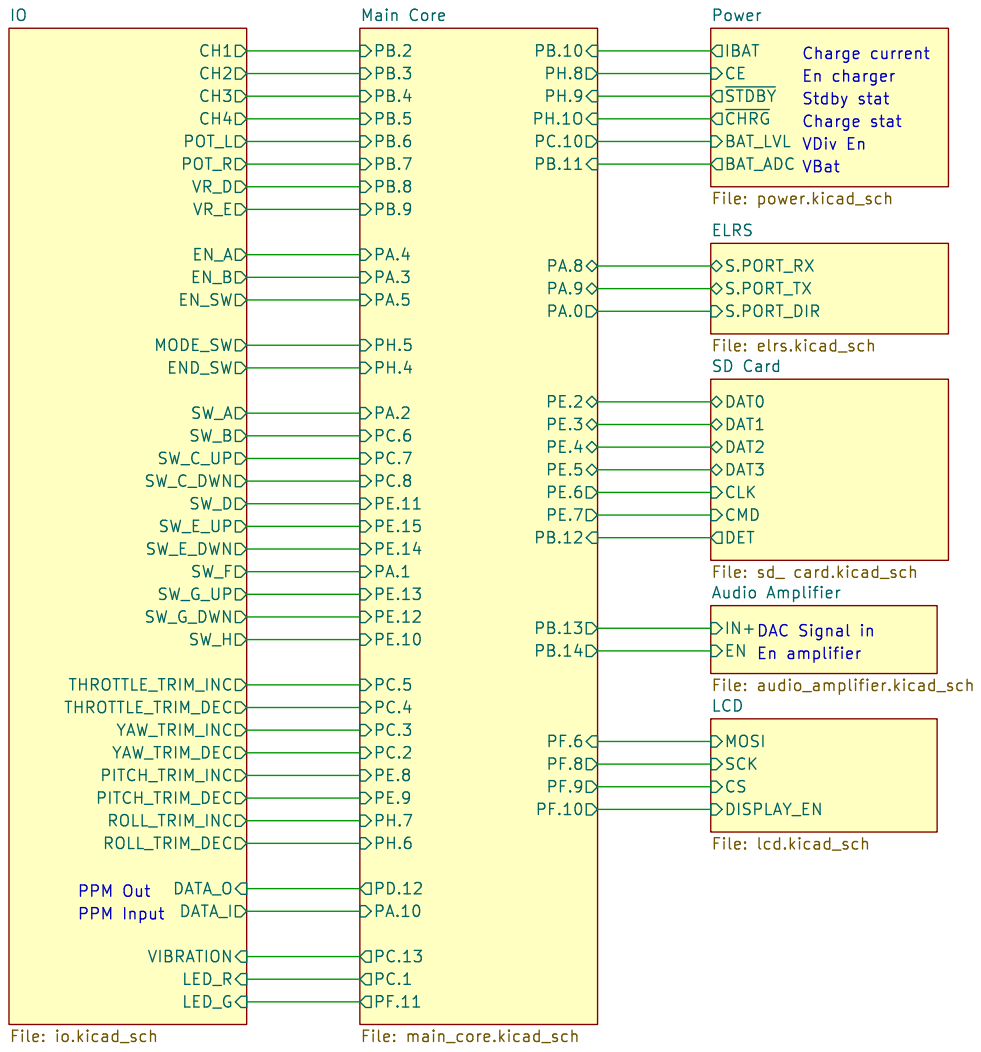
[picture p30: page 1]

PB.11 PC.10 Main Core
Charge stat DAC Signal in En charger VDiv En VBat Stdby stat Charge current En amplifier
SD Card File: sd_ card.kicad_sch ~{STDBY}
~{CHRG}
BAT_LVL BAT_ADC
File: lcd.kicad_sch DAT0 DAT1 DET CMD

File: elrs.kicad_sch PPM Out PPM Input

Audio Amplifier File: audio_amplifier.kicad_sch CSDISPLAY_EN MOSI SCK

Alperen þÿKOLAMUÇ
alperen.kolamu@gmail.com

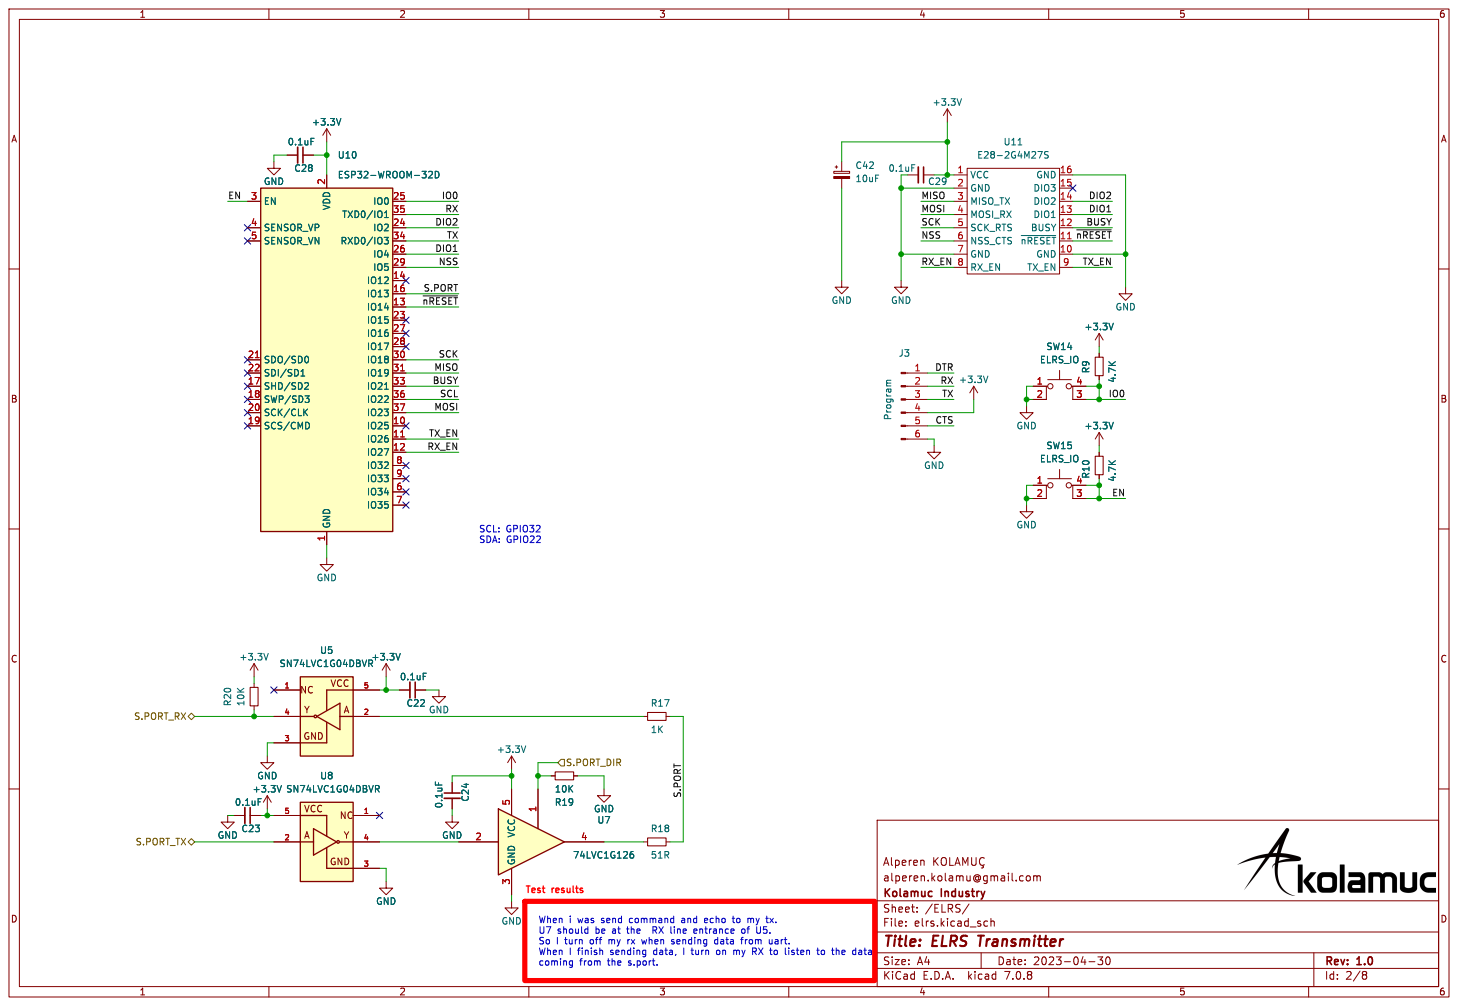
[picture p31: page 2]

alperen.kolamu@gmail.com

coming from the s.port. | Industry Id: 2/8 Title: ELRS Transmitter File: elrs.kicad_sch Sheet: /ELRS/ Kolamuc

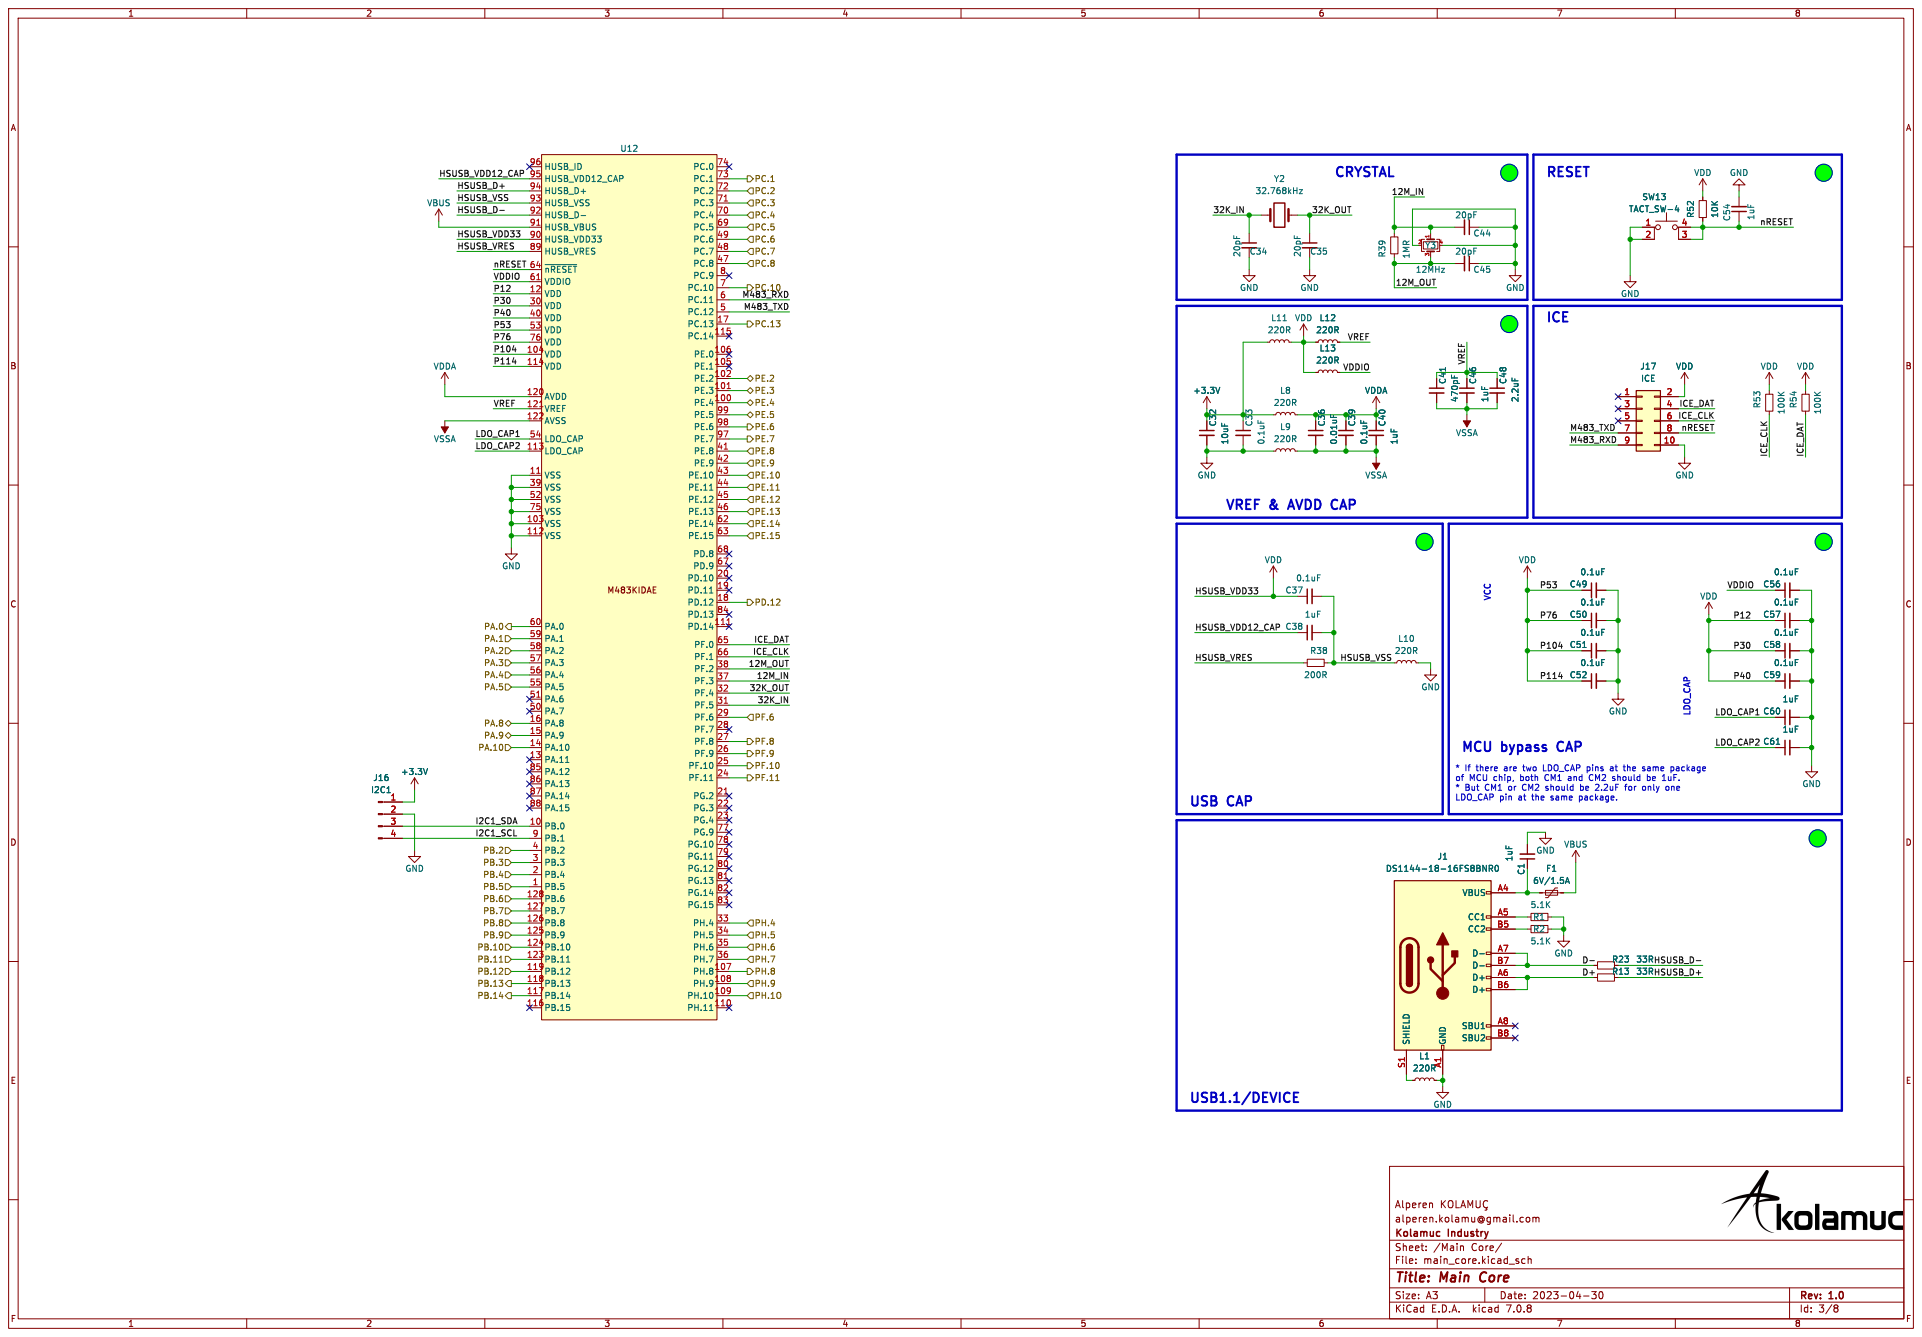
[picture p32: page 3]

P104 P114 P53 HSUSB_VSS
HUSB_VRES 89
12MHz PA.10
VDD 12 AVDD 120 VREF 121 AVSS 122 PB.11 123 PB.10 124 PB.9 125 PB.8 126 PB.7 127 PB.6 128 PA.11 13 PA.10 14 PA.9 15 PA.8 16

ICE_DAT M483_RXD M483_TXD

of MCU chip, both CM1 and CM2 should be 1uF. * But CM1 or CM2 should be 2.2uF for only one

LDO_CAP pin at the same package.

alperen.kolamu@gmail.com

Id: 3/8 Title: Main Core

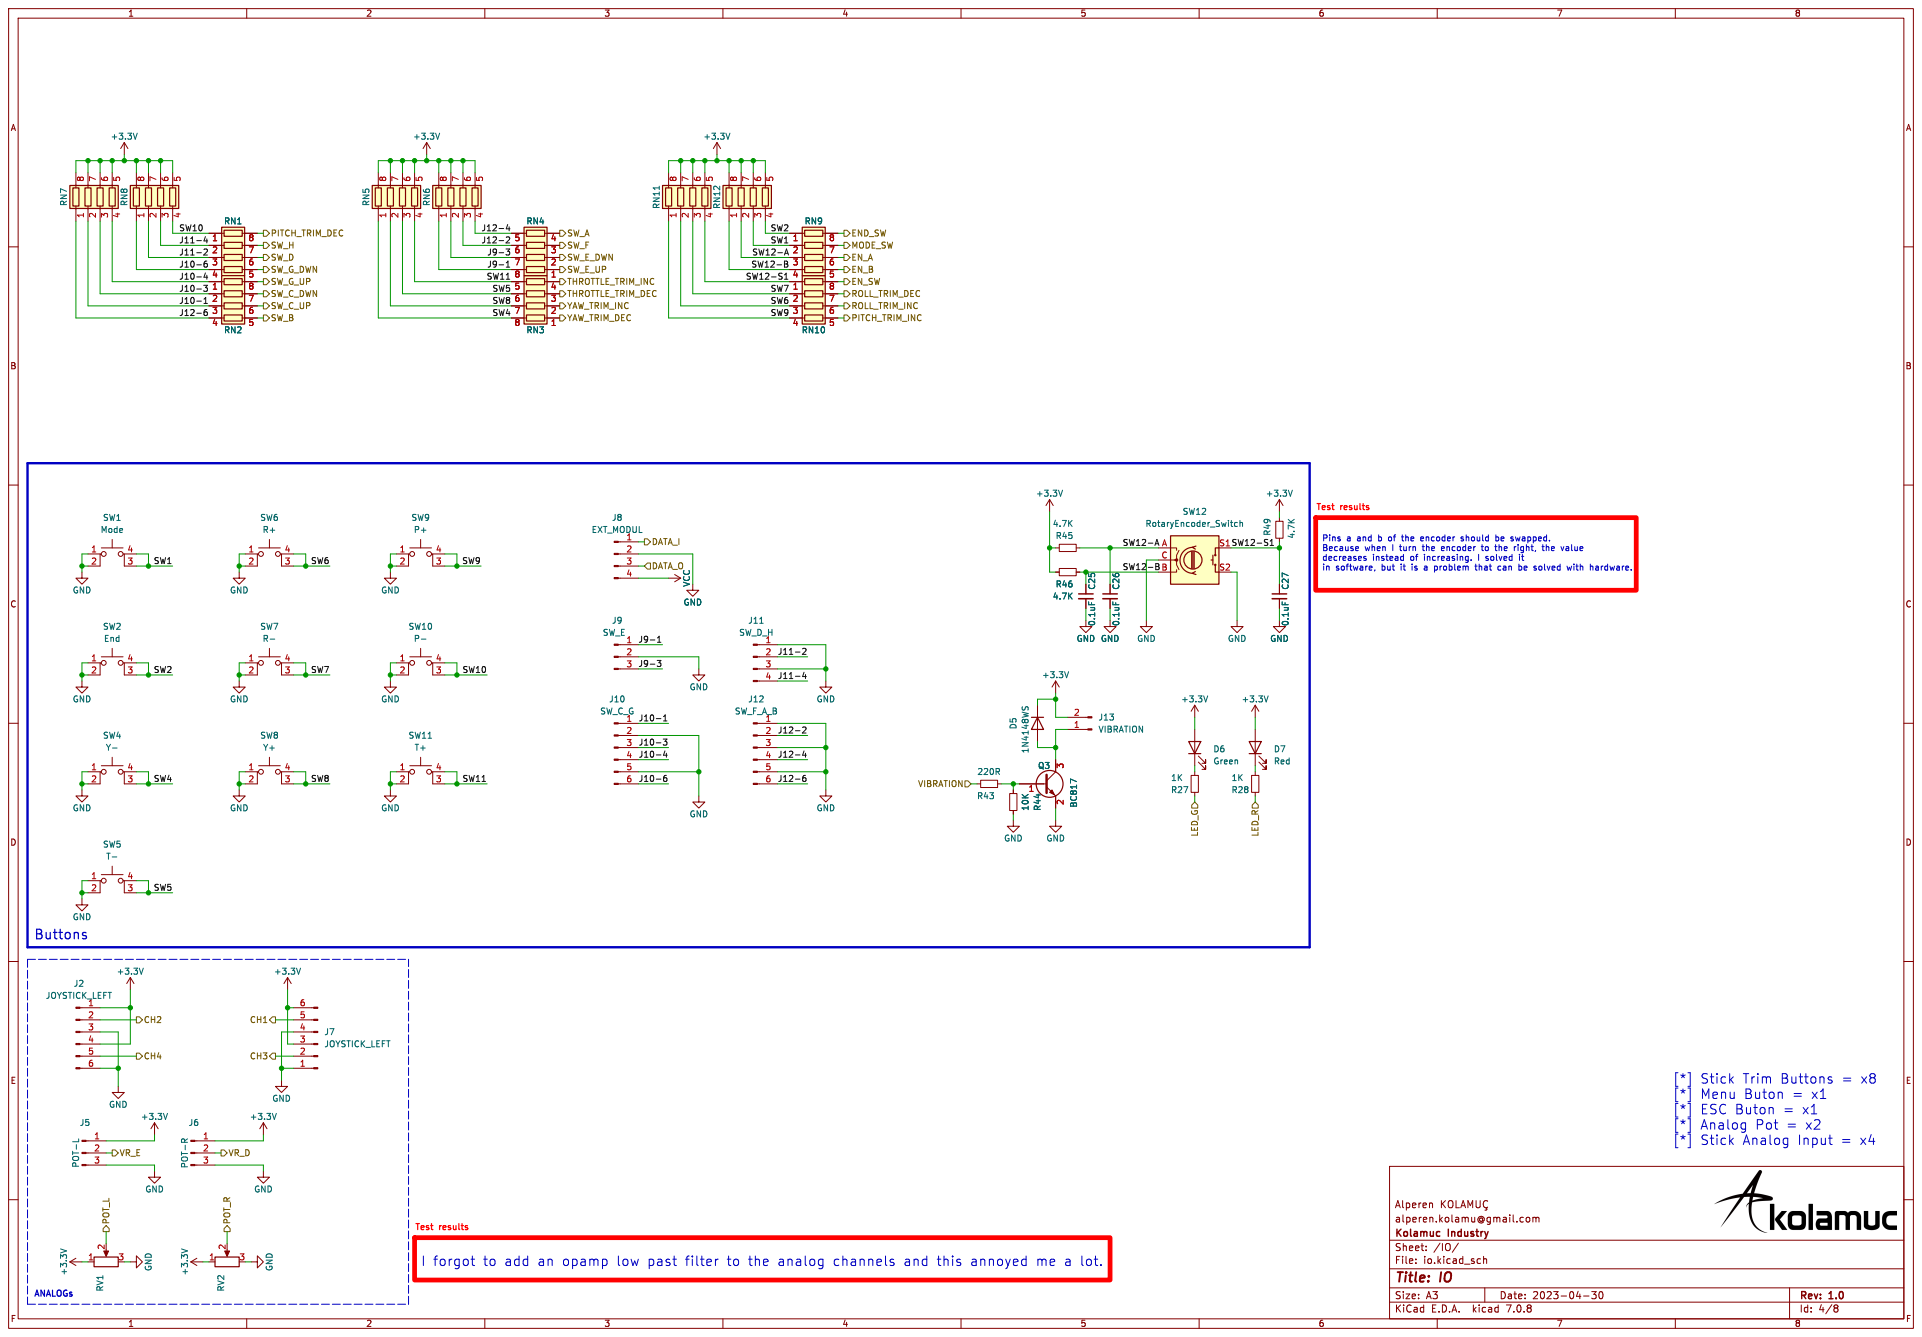
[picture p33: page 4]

Pins a and b of the encoder should be swapped. Because when I turn the encoder to the right, the value

alperen.kolamu@gmail.com

I forgot to add an opamp low past filter to the analog channels and this annoyed me a lot.

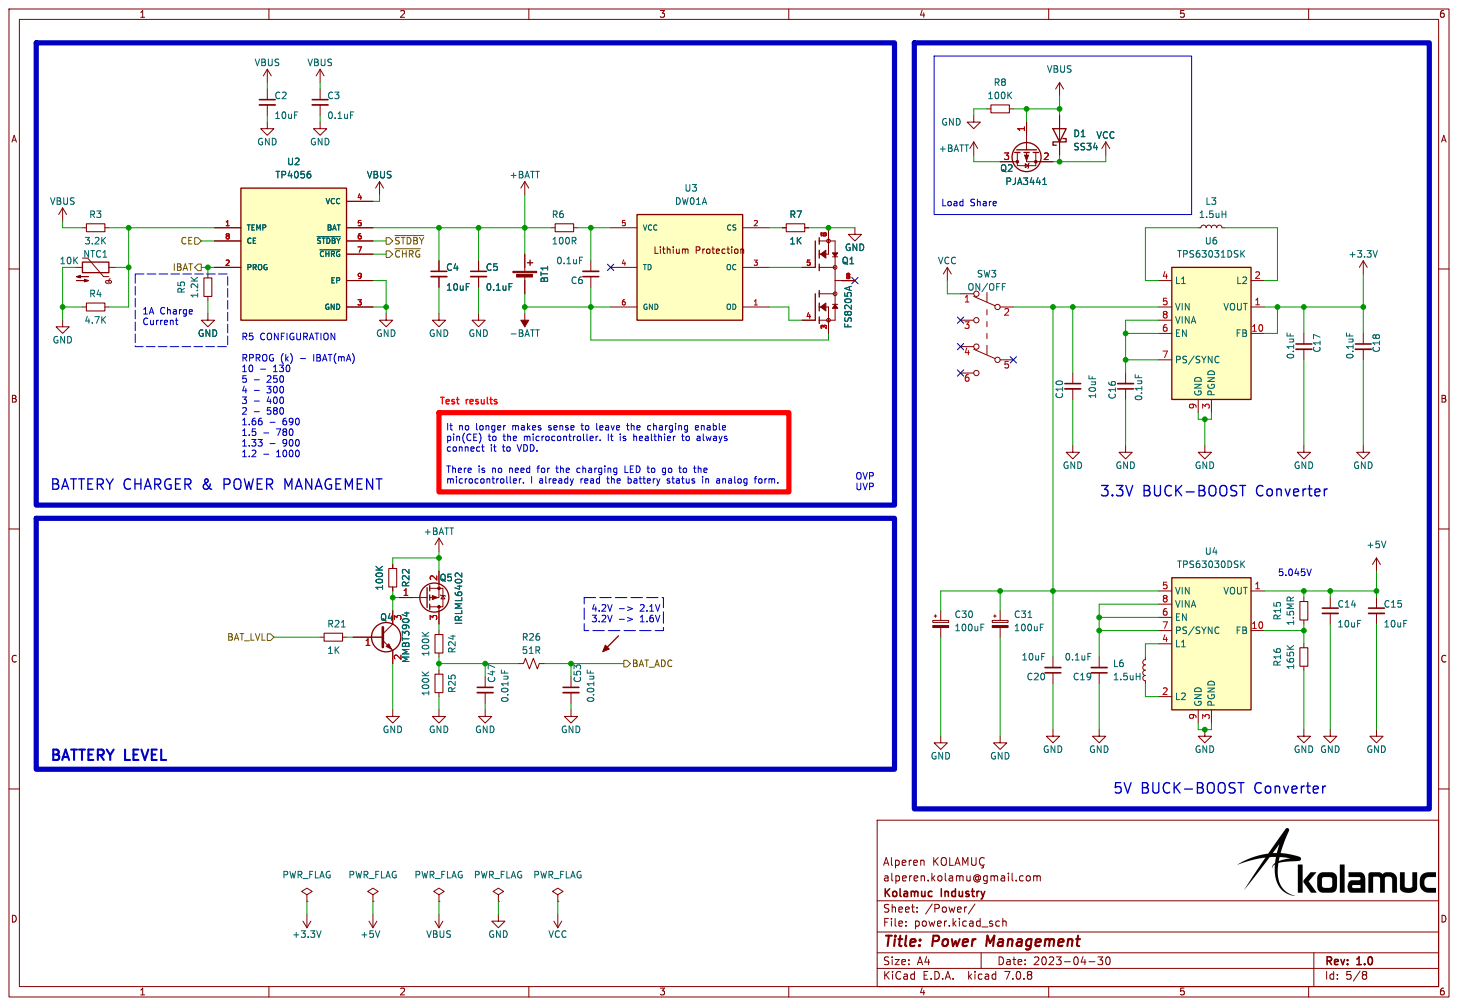
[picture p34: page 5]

1.2 - 1000 BATTERY CHARGER & POWER MANAGEMENT

Alperen þÿKOLAMUÇ alperen.kolamu@gmail.com

Industry Id: 5/8 Title: Power Management File: power.kicad_sch Sheet: /Power/ Kolamuc

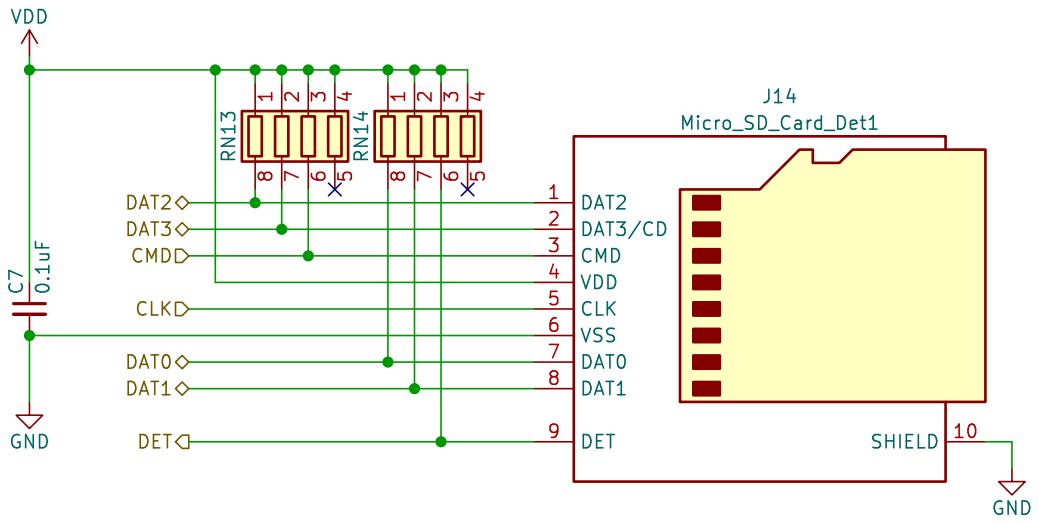
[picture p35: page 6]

5 RN14 DAT2 1 SHIELD 10 DAT3/CD 2 CMD 3 VDD 4 CLK 5 VSS 6 DAT0 7 DAT1 8 DET 9

Alperen þÿKOLAMUÇ
alperen.kolamu@gmail.com

Id: 6/8 Title: uSD Card

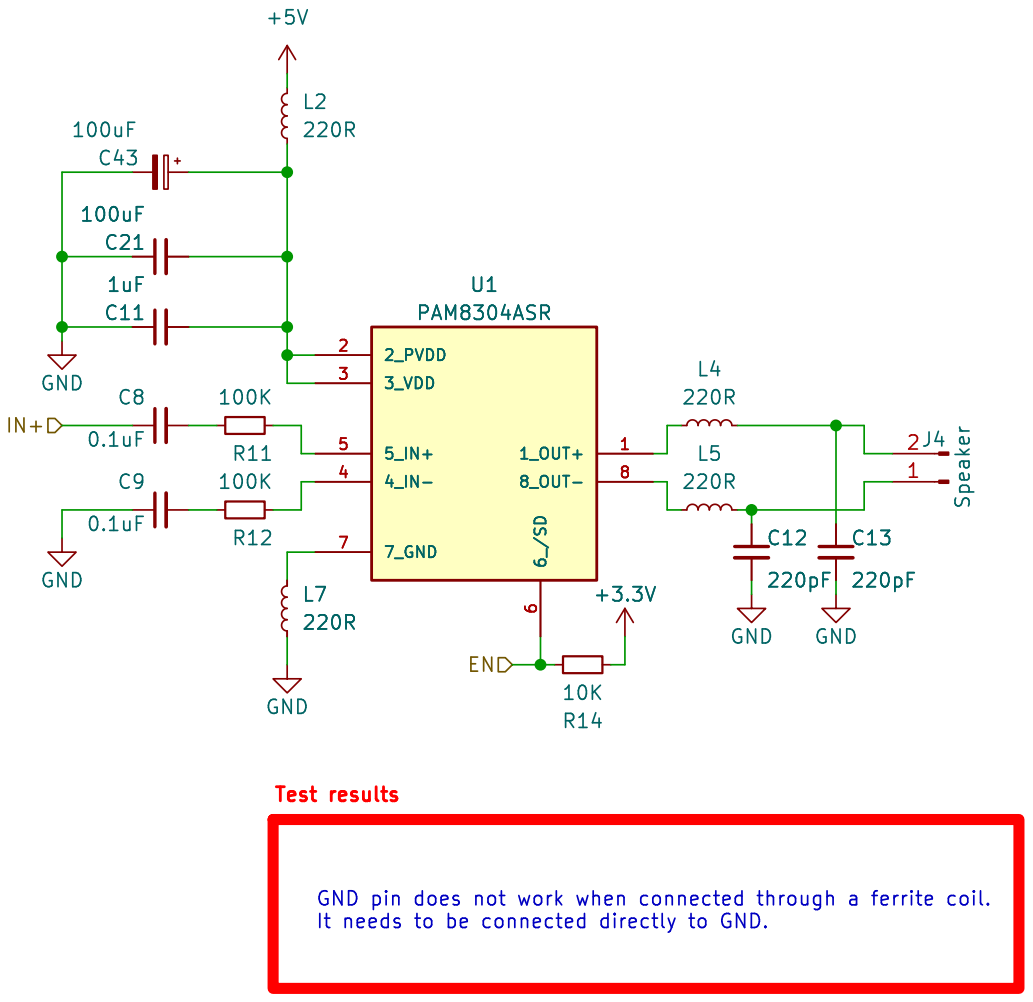
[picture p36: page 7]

Alperen þÿKOLAMUÇ alperen.kolamu@gmail.com

Industry | Amplifier/ Kolamuc Id: 7/8 Title: Audio Amplifier File: audio_amplifier.kicad_sch Sheet: /Audio

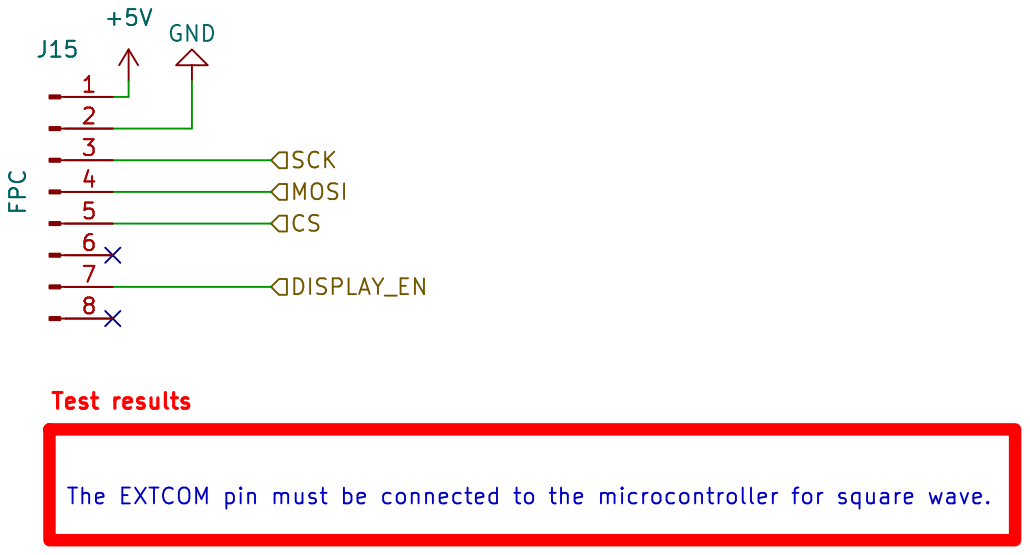
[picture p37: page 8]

Alperen þÿKOLAMUÇ
alperen.kolamu@gmail.com

Id: 8/8 Title: Sharp Memory Display

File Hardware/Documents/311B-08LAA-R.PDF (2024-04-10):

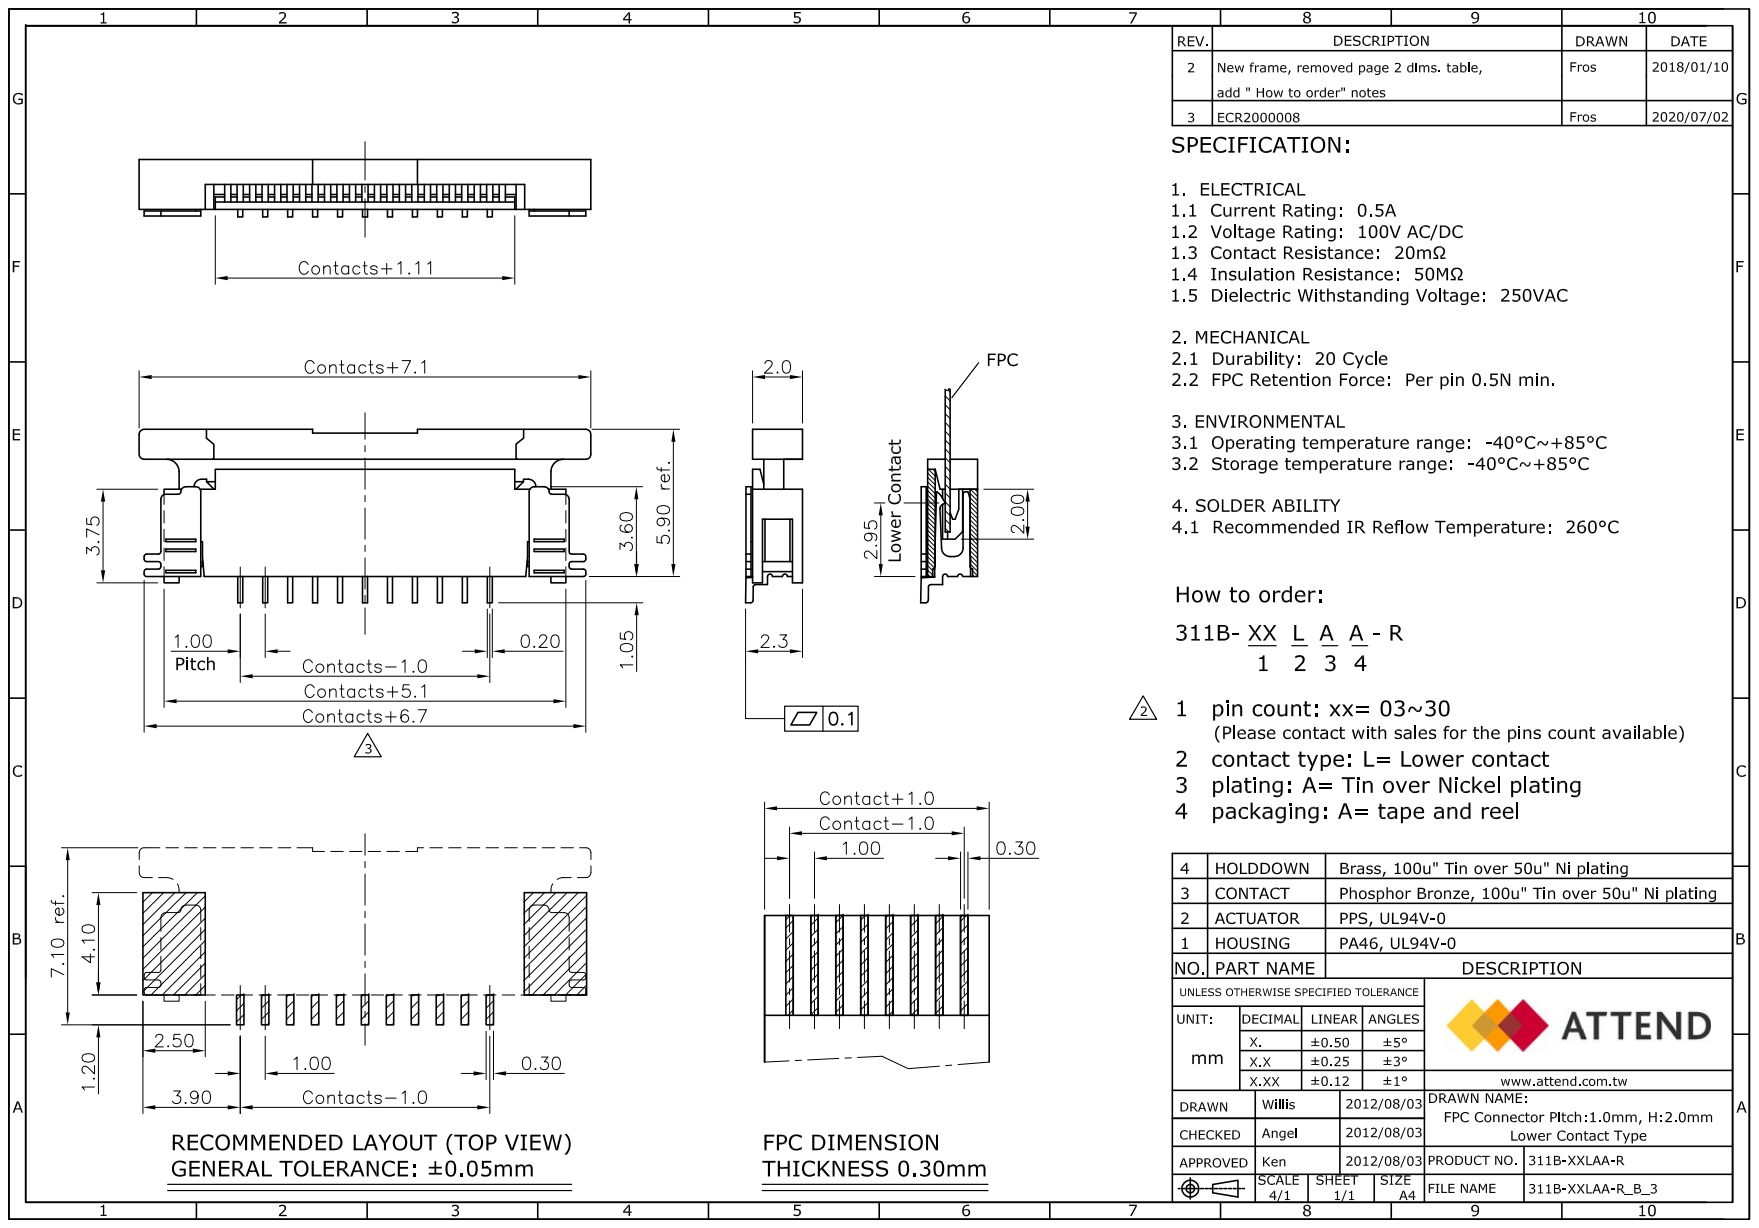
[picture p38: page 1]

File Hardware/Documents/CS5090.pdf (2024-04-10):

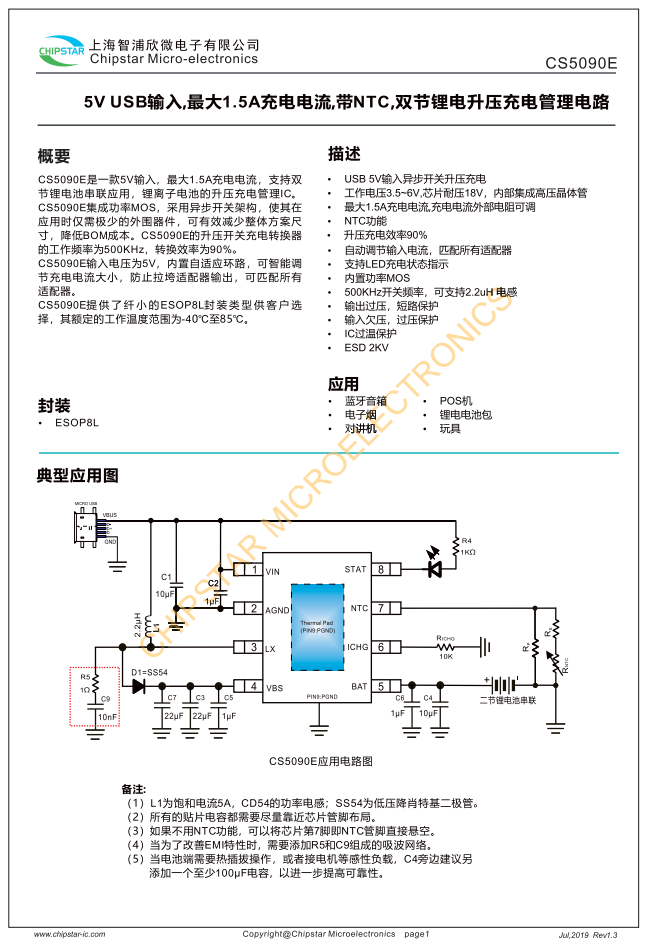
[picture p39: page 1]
CHIPSTAR; MICROELECTRONICS S

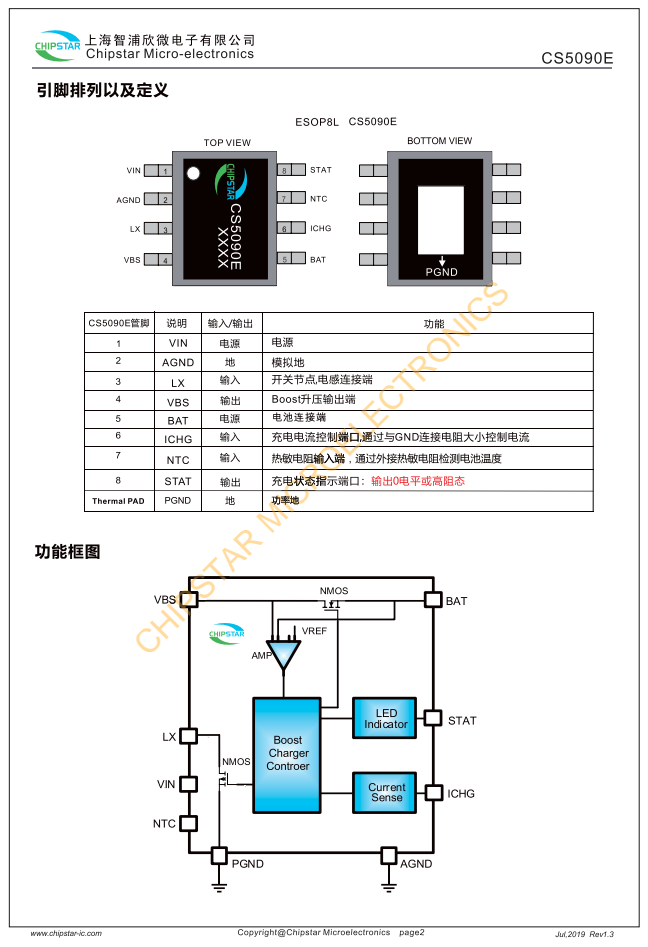
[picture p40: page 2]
CHIPSTARMICROELECTRONICS

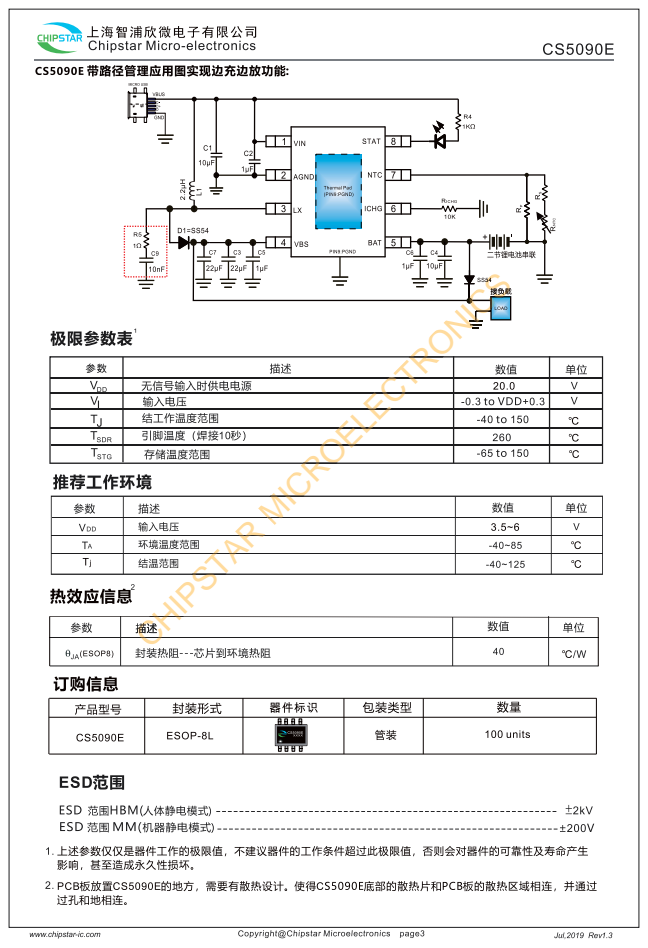
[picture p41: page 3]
CHIPSTARCH; MICROELECTRONICS

CHIPSTAR; MICROELECTRONICS

CHIPSTAR CHIPSTA; MICROELECTRONICS

MICROELECTRONICS

CHIPSTARMICROELECTRONICS

CHIPSTAR; MICROELECTRONICS

MICROELECTRONICS



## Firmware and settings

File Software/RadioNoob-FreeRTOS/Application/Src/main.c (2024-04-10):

/**************************************************************************//**
 * @file     main.c
 * @version  V3.00
 * @brief    Show how to set GPIO pin mode and use pin data input/output control.
 *
 * @copyright (C) 2013~2015 Nuvoton Technology Corp. All rights reserved.
 *
 ******************************************************************************/

#include "main.h"

extern TableParams myTableParams;
extern RCValues myRCvalues;

void SYS_Init(void);
void UART0_Init(void);
void TIMER0_Init(void);
void TIMER1_Init(void);
void TIMER2_Init(void);
void EPWM0_Init(void);
void GPIO_Init(void);
void SPI_Init(void);
void QEI0_Init(void);
void QEI0_Init_Index(uint32_t index);


int32_t main(void)
{

    /* Unlock protected registers */
    SYS_UnlockReg();

    /* Init System, peripheral clock and multi-function I/O */
    SYS_Init();
	
    /* Lock protected registers */
    SYS_LockReg();

    /* Init UART0 for printf */
    UART0_Init();
	
		/* Init TIMER0 for EADC */
    TIMER0_Init();
	
		/* Init TIMER1 for Delay */
		TIMER1_Init();
		
		/* Init SPI */
    SPI_Init();
		
		/* Init QEI */
		QEI0_Init_Index(0x08);
		
		/* Init GPIO */
		GPIO_Init();
		
		CRSF_Begin();
		
		printf("RadiolinkAT9C	V:%s\n", VERSION);
    printf("Running on @%dMHz\n", SystemCoreClock/1000000);

		setDataFlashBase(DATA_FLASH_BASE_ADDR);
		
		TableReadToFlash(DATA_FLASH_BASE_ADDR, &myTableParams);
		if(myTableParams.MainConfig.calibStat == 0xFF)
			printf("Fresh EEPROM Calibration!\n");

		printf("Main Task is creating ...\n");
		xTaskCreate(vCheckTask, "Main Task",  mainCHECK_TASK_STACK_SIZE, NULL, mainCHECK_TASK_PRIORITY, NULL);

		printf("LCD Task is creating ...\n");
		xTaskCreate(vLcdTask, "LCD Task",  mainLCD_TASK_STACK_SIZE, NULL, mainLCD_TASK_PRIORITY, NULL);
		
		printf("FreeRTOS is starting ...\n\n");
		
		vTaskStartScheduler();

		for(;;);
		
		/* Application Setup */
		
		return 0;
}


/* FreeRTOS Functions Implemantation*/

void vCheckTask(void *pvParameters) {
	
	/* Task Setup */

	/* Task Loop */
	
	for (;;) 
	{
		Get_ADC();
		gpioMixer();
		CRSF_Update();
		serialEvent();
	}
}

void vLcdTask(void *pvParameters) {
	
	/* Task Setup */
	GUI_Init();
	/* Task Loop */
	
	for (;;) {
//		LED_GREEN_PIN = !LED_GREEN_PIN;
		GUI_Update();
//		TaskStatus_t xTaskStatus;
//    // Görevin bilgilerini al
//    vTaskGetInfo(NULL, &xTaskStatus, pdTRUE, eRunning);
//		printf("Task Name: %s, Task State: %d, Task Priority: %d\n", 
//           xTaskStatus.pcTaskName, xTaskStatus.eCurrentState, xTaskStatus.uxCurrentPriority);
//		vTaskDelay(500);
	}
	
}

void SYS_Init(void)
{
    /* Set XT12_OUT(PF.2) and XT1_IN(PF.3) to input mode */
    SYS->GPF_MFPL &= ~(SYS_GPF_MFPL_PF3MFP_Msk | SYS_GPF_MFPL_PF2MFP_Msk);
    SYS->GPF_MFPL |= (SYS_GPF_MFPL_PF3MFP_XT1_IN | SYS_GPF_MFPL_PF2MFP_XT1_OUT);
	
		/* Set XT32_OUT(PF.5) and XT1_IN(PF.4) to input mode */
		SYS->GPF_MFPL &= ~(SYS_GPF_MFPL_PF5MFP_Msk | SYS_GPF_MFPL_PF4MFP_Msk);
    SYS->GPF_MFPL |= (SYS_GPF_MFPL_PF5MFP_X32_IN | SYS_GPF_MFPL_PF4MFP_X32_OUT);

    /* Enable External XTAL (4~24 MHz) */
    CLK_EnableXtalRC(CLK_PWRCTL_HXTEN_Msk);

    /* Waiting for 12MHz clock ready */
    CLK_WaitClockReady(CLK_STATUS_HXTSTB_Msk);

    /* Switch HCLK clock source to HXT */
    CLK_SetHCLK(CLK_CLKSEL0_HCLKSEL_HXT,CLK_CLKDIV0_HCLK(1));

    /* Set core clock as PLL_CLOCK from PLL */
    CLK_SetCoreClock(FREQ_192MHZ);

    /* Set both PCLK0 and PCLK1 as HCLK/2 */
    CLK->PCLKDIV = CLK_PCLKDIV_APB0DIV_DIV2 | CLK_PCLKDIV_APB1DIV_DIV2;

	  //Modul clock settings
    /* Enable UART0 module clock */
    CLK_EnableModuleClock(UART0_MODULE);
		
		/* Enable UART1 module clock */
    CLK_EnableModuleClock(UART1_MODULE);
		
		/* Enable Timer 0 module clock */
    CLK_EnableModuleClock(TMR0_MODULE);
		
		/* Enable TIMER1 module clock */
		CLK_EnableModuleClock(TMR1_MODULE);
		
		/* Enable TIMER2 module clock */
		CLK_EnableModuleClock(TMR2_MODULE);
		
		/* Enable EPWM0 module clock */
    CLK_EnableModuleClock(EPWM0_MODULE);
		
		/* Enable QEI0 module clock */
		CLK_EnableModuleClock(QEI0_MODULE);
		
		/* Enable EADC module clock */
    CLK_EnableModuleClock(EADC_MODULE);
		
		/* Enable SPI0 peripheral clock */
    CLK_EnableModuleClock(SPI0_MODULE);
		
		/* Enable SHD0 clock */
		CLK_EnableModuleClock(SDH0_MODULE);
		
		/* Enable PDMA clock */
		CLK_EnableModuleClock(PDMA_MODULE);
		
		/* Enable DAC module clock */
    CLK_EnableModuleClock(DAC_MODULE);
		
		/* Reset DAC modul */
		SYS_ResetModule(DAC_MODULE);
				
		
		//Clock selections
    /* Select UART module clock source as HXT and UART module clock divider as 1 */
    CLK_SetModuleClock(UART0_MODULE, CLK_CLKSEL1_UART0SEL_HXT, CLK_CLKDIV0_UART0(1));
		
		/* Select UART module clock source */
		CLK_SetModuleClock(UART1_MODULE, CLK_CLKSEL1_UART0SEL_HXT, CLK_CLKDIV0_UART1(1));
		
		/* Select TIMER0 module clock source as HXT */
    CLK_SetModuleClock(TMR0_MODULE, CLK_CLKSEL1_TMR0SEL_HXT, 0);
		
		/* Select TIMER1 module clock source as HXT and UART module clock divider as 1 */
		CLK_SetModuleClock(TMR1_MODULE, CLK_CLKSEL1_TMR1SEL_HXT, 0);
		
		/* Select TIMER1 module clock source as HXT and UART module clock divider as 1 */
		CLK_SetModuleClock(TMR2_MODULE, CLK_CLKSEL1_TMR2SEL_HXT, 0);
		
		/* Select EPWM0 module clock source as PCLK0 */
    CLK_SetModuleClock(EPWM0_MODULE, CLK_CLKSEL2_EPWM0SEL_PCLK0, 0);
		
		/* EADC clock source is 96MHz, set divider to 8, EADC clock is 96/8 MHz */
    CLK_SetModuleClock(EADC_MODULE, 0, CLK_CLKDIV0_EADC(8));
		
		/* Select PCLK as the clock source of SPI0 and SPI1 */
    CLK_SetModuleClock(SPI0_MODULE, CLK_CLKSEL2_SPI0SEL_HXT, MODULE_NoMsk);
		
		/* Select SHD0 clock source */
		CLK_SetModuleClock(SDH0_MODULE, CLK_CLKSEL0_SDH0SEL_PLL, CLK_CLKDIV0_SDH0(10));
		
		/* Reset Module*/
		SYS_ResetModule(SDH0_MODULE);
		
		/* Update System Core Clock */
		/* User can use SystemCoreClockUpdate() to calculate PllClock, SystemCoreClock and CycylesPerUs automatically. */
		SystemCoreClockUpdate();
		
		//Multi-Function pins settings
    /* Set GPB multi-function pins for UART0 RXD and TXD */
    SYS->GPC_MFPH &= ~(SYS_GPC_MFPH_PC12MFP_Msk | SYS_GPC_MFPH_PC11MFP_Msk);
    SYS->GPC_MFPH |= (SYS_GPC_MFPH_PC12MFP_UART0_TXD | SYS_GPC_MFPH_PC11MFP_UART0_RXD);
		
		/* Set GPA multi-function pins for UART1 RXD, TXD and RTS*/
		SYS->GPA_MFPH &= ~(SYS_GPA_MFPH_PA9MFP_Msk | SYS_GPA_MFPH_PA8MFP_Msk);
    SYS->GPA_MFPH |= (SYS_GPA_MFPH_PA9MFP_UART1_TXD | SYS_GPA_MFPH_PA8MFP_UART1_RXD);
//    SYS->GPA_MFPL &= ~(SYS_GPA_MFPL_PA0MFP_Msk);
//    SYS->GPA_MFPL |= (SYS_GPA_MFPL_PA0MFP_UART1_nRTS);
		
		/* Set GPF multi-function pins for ICE_DAT and ICE_CLK */
		SYS->GPF_MFPL &= ~(SYS_GPF_MFPL_PF1MFP_Msk | SYS_GPF_MFPL_PF0MFP_Msk);
    SYS->GPF_MFPL |= (SYS_GPF_MFPL_PF1MFP_ICE_CLK | SYS_GPF_MFPL_PF0MFP_ICE_DAT);
		
		/* Set PA multi-function pins for QEI0_A, QEI0_B, QEI0_INDEX */
		SYS->GPA_MFPL &= ~(SYS_GPA_MFPL_PA4MFP_Msk | SYS_GPA_MFPL_PA3MFP_Msk | SYS_GPA_MFPL_PA5MFP_Msk);
		SYS->GPA_MFPL |= (SYS_GPA_MFPL_PA4MFP_QEI0_A | SYS_GPA_MFPL_PA3MFP_QEI0_B | SYS_GPA_MFPL_PA5MFP_QEI0_INDEX);
		
//		/* Enable temperature sensor */
//    SYS->IVSCTL |= SYS_IVSCTL_VTEMPEN_Msk;
		
		
		
				/* Set PB.2 ~ PB.11 to input mode */
    PB->MODE &= ~(GPIO_MODE_MODE2_Msk | GPIO_MODE_MODE3_Msk | GPIO_MODE_MODE4_Msk | 
									GPIO_MODE_MODE5_Msk | GPIO_MODE_MODE6_Msk | GPIO_MODE_MODE7_Msk | 
									GPIO_MODE_MODE8_Msk | GPIO_MODE_MODE9_Msk | GPIO_MODE_MODE10_Msk | 
									GPIO_MODE_MODE11_Msk);
									
	  /* Configure the GPB2 - GPB3 EADC1 analog input pins.  */
    SYS->GPB_MFPL &= ~(SYS_GPB_MFPL_PB2MFP_Msk | SYS_GPB_MFPL_PB3MFP_Msk |
                       SYS_GPB_MFPL_PB4MFP_Msk | SYS_GPB_MFPL_PB5MFP_Msk | 
											 SYS_GPB_MFPL_PB6MFP_Msk | SYS_GPB_MFPL_PB7MFP_Msk );
											 
		/* Configure the GPB8 - GPB11 EADC1 analog input pins.  */									 
		SYS->GPB_MFPH &= ~(SYS_GPB_MFPH_PB8MFP_Msk | SYS_GPB_MFPH_PB9MFP_Msk |
											 SYS_GPB_MFPH_PB10MFP_Msk | SYS_GPB_MFPH_PB11MFP_Msk);				

		SYS->GPB_MFPL |= (SYS_GPB_MFPL_PB2MFP_EADC0_CH2 | SYS_GPB_MFPL_PB3MFP_EADC0_CH3 |
											SYS_GPB_MFPL_PB4MFP_EADC0_CH4 | SYS_GPB_MFPL_PB5MFP_EADC0_CH5 |
											SYS_GPB_MFPL_PB6MFP_EADC0_CH6 | SYS_GPB_MFPL_PB7MFP_EADC0_CH7 );
		SYS->GPB_MFPH |= (SYS_GPB_MFPH_PB8MFP_EADC0_CH8 | SYS_GPB_MFPH_PB9MFP_EADC0_CH9 |
											SYS_GPB_MFPH_PB10MFP_EADC0_CH10 | SYS_GPB_MFPH_PB11MFP_EADC0_CH11);

		/* Disable the GPB2 - GPB11 digital input path to avoid the leakage current. */
    GPIO_DISABLE_DIGITAL_PATH(PB, BIT11|BIT10|BIT9|BIT8|BIT7|BIT6|BIT5|BIT4|BIT3|BIT2);
		
		/* Enable SPI0 clock pin (PF8) schmitt trigger */
    PF->SMTEN |= GPIO_SMTEN_SMTEN2_Msk;
		/* Enable SPI0 I/O high slew rate */
    GPIO_SetSlewCtl(PF, 0xF, GPIO_SLEWCTL_HIGH);
		/* Setup SPI0 multi-function pins */
		SYS->GPF_MFPL &= ~(SYS_GPF_MFPL_PF6MFP_Msk);
    SYS->GPF_MFPL |= (SYS_GPF_MFPL_PF6MFP_SPI0_MOSI);
		
		SYS->GPF_MFPH &= ~(SYS_GPF_MFPH_PF8MFP_Msk);
		SYS->GPF_MFPH |= (SYS_GPF_MFPH_PF8MFP_SPI0_CLK);
		
		
		/* Setup SD0 MFP */
		SYS->GPE_MFPL &= ~(SYS_GPE_MFPL_PE7MFP_Msk | 
										 SYS_GPE_MFPL_PE6MFP_Msk | 
										 SYS_GPE_MFPL_PE2MFP_Msk | 
										 SYS_GPE_MFPL_PE3MFP_Msk | 
										 SYS_GPE_MFPL_PE4MFP_Msk | 
										 SYS_GPE_MFPL_PE5MFP_Msk);
	
		SYS->GPE_MFPL |= (SYS_GPE_MFPL_PE7MFP_SD0_CMD | 
											SYS_GPE_MFPL_PE6MFP_SD0_CLK | 
											SYS_GPE_MFPL_PE2MFP_SD0_DAT0 | 
											SYS_GPE_MFPL_PE3MFP_SD0_DAT1 | 
											SYS_GPE_MFPL_PE4MFP_SD0_DAT2 |
											SYS_GPE_MFPL_PE5MFP_SD0_DAT3);
		
		SYS->GPB_MFPH &= ~(SYS_GPB_MFPH_PB12MFP_Msk);
		SYS->GPB_MFPH |= (SYS_GPB_MFPH_PB12MFP_SD0_nCD);
		
		
		/* Setup DAC MFP */
		SYS->GPB_MFPH &= ~(SYS_GPB_MFPH_PB13MFP_Msk);
		SYS->GPB_MFPH |= (SYS_GPB_MFPH_PB13MFP_DAC1_OUT);


    /* Disable digital input path of analog pin DAC1_OUT to prevent leakage */
    GPIO_DISABLE_DIGITAL_PATH(PB, (1ul << 13));

}

void UART0_Init(void)
{
		/* Reset UART module */
		SYS_ResetModule(UART0_RST);
    /* Configure UART0 and set UART0 baud rate */
    UART_Open(UART0, 115200);
}


void TIMER0_Init(void)
{
    /* Set timer0 periodic time-out period is 3us if timer clock is 12 MHz */
    TIMER_SET_CMP_VALUE(TIMER0, 36);//TIMER0->CMP = 36;

    /* Start timer counter in periodic mode and enable timer interrupt trigger EADC */
    TIMER0->CTL = TIMER_PERIODIC_MODE;
    TIMER0->TRGCTL |= TIMER_TRGCTL_TRGEADC_Msk;
}

void TIMER1_Init(void)
{
		/* Open Timer1 in periodic mode, enable interrupt and 2 interrupt ticks per second */
    TIMER_Open(TIMER1, TIMER_PERIODIC_MODE, 1000000);
    TIMER_EnableInt(TIMER1);
		NVIC_EnableIRQ(TMR1_IRQn);
		TIMER_Start(TIMER1);
}

void EPWM0_Init(void)
{

    /* Set EPWM0 timer clock prescaler */
    EPWM_SET_PRESCALER(EPWM0, 0, 10);

    /* Set up counter type */
    EPWM0->CTL1 &= ~EPWM_CTL1_CNTTYPE0_Msk;

    /* Set EPWM0 timer duty */
    EPWM_SET_CMR(EPWM0, 0, 1000);

    /* Set EPWM0 timer period */
    EPWM_SET_CNR(EPWM0, 0, 2000);

    /* EPWM period point trigger ADC enable */
    EPWM_EnableADCTrigger(EPWM0, 0, EPWM_TRG_ADC_EVEN_PERIOD);

    /* Set output level at zero, compare up, period(center) and compare down of specified channel */
    EPWM_SET_OUTPUT_LEVEL(EPWM0, BIT0, EPWM_OUTPUT_HIGH, EPWM_OUTPUT_LOW, EPWM_OUTPUT_NOTHING, EPWM_OUTPUT_NOTHING);

    /* Enable output of EPWM0 channel 0 */
    EPWM_EnableOutput(EPWM0, BIT0);

}


void GPIO_Init(void)
{
		// Outputs
		GPIO_SetMode(VIB_MTR_PORT, VIBRATION_MTR_BIT, GPIO_MODE_OUTPUT);
		GPIO_SetMode(LED_GREEN_PORT, LED_GREEN_BIT, GPIO_MODE_OUTPUT);
	  GPIO_SetMode(LED_RED_PORT, LED_RED_BIT, GPIO_MODE_OUTPUT);
		GPIO_SetMode(CHRG_PORT, CHRG_EN_BIT, GPIO_MODE_OUTPUT);
		GPIO_SetMode(BAT_LVL_PORT, BAT_LVL_BIT, GPIO_MODE_OUTPUT);
		GPIO_SetMode(DISPLAY_EN_PORT, DISPLAY_EN_BIT, GPIO_MODE_OUTPUT);
	  GPIO_SetMode(SPI0_CS_PORT, SPI0_CS_BIT, GPIO_MODE_OUTPUT);
	  GPIO_SetMode(AUDIO_EN_PORT, AUDIO_EN_BIT, GPIO_MODE_OUTPUT);
		GPIO_SetMode(UART1_DIR_PORT, UART1_DIR_BIT, GPIO_MODE_OUTPUT);
		GPIO_SetMode(DISPLAY_EXCOM_PORT, DISPLAY_EXCOM_BIT, GPIO_MODE_OUTPUT);
	
		// Inputs
		GPIO_SetMode(MODE_SW_PORT, MODE_SW_BIT, GPIO_MODE_INPUT);
		GPIO_SetMode(END_SW_PORT, END_SW_BIT, GPIO_MODE_INPUT);
		GPIO_SetMode(SW_A_PORT, SW_A_BIT, GPIO_MODE_INPUT);
		GPIO_SetMode(SW_B_PORT, SW_B_BIT, GPIO_MODE_INPUT);
		GPIO_SetMode(SW_C_PORT, SW_C_UP_BIT | SW_C_DWN_BIT, GPIO_MODE_INPUT);
		GPIO_SetMode(SW_D_PORT, SW_D_BIT, GPIO_MODE_INPUT);
		GPIO_SetMode(SW_E_PORT, SW_E_UP_BIT | SW_E_DWN_BIT, GPIO_MODE_INPUT);
		GPIO_SetMode(SW_F_PORT, SW_F_BIT, GPIO_MODE_INPUT);
		GPIO_SetMode(SW_G_PORT, SW_G_UP_BIT | SW_G_DWN_BIT, GPIO_MODE_INPUT);
		GPIO_SetMode(SW_H_PORT, SW_H_BIT, GPIO_MODE_INPUT);
		GPIO_SetMode(T_TRM_PORT, T_TRM_INC_BIT | T_TRM_DEC_BIT, GPIO_MODE_INPUT);
		GPIO_SetMode(Y_TRM_PORT, Y_TRM_INC_BIT | Y_TRM_DEC_BIT, GPIO_MODE_INPUT);
		GPIO_SetMode(P_TRM_PORT, P_TRM_INC_BIT | P_TRM_DEC_BIT, GPIO_MODE_INPUT);
		GPIO_SetMode(R_TRM_PORT, R_TRM_INC_BIT | R_TRM_DEC_BIT, GPIO_MODE_INPUT);
		GPIO_SetMode(CHRG_PORT, CHRG_STDBY_BIT | CHRG_STAT_BIT, GPIO_MODE_INPUT);
		GPIO_SetMode(ENCODER_SW_PORT, ENCODER_SW_BIT, GPIO_MODE_INPUT);
		
		
				
		CHRG_EN_PIN = 1;
		LED_GREEN_PIN = 1;
		LED_RED_PIN = 1;
		VIB_MTR_PIN = 0;
		BAT_LVL_PIN = 0;
		DISPLAY_EN_PIN = 0;
		SPI0_CS_PIN = 0;
		AUDIO_EN = 0;

}


void SPI_Init(void)
{
    /*---------------------------------------------------------------------------------------------------------*/
    /* Init SPI                                                                                                */
    /*---------------------------------------------------------------------------------------------------------*/
    /* Configure as a master, clock idle low, 8-bit transaction, drive output on falling clock edge and latch input on rising edge. */
    /* Set IP clock divider. SPI clock rate = 1MHz */
    SPI_Open(SPI0, SPI_MASTER, SPI_MODE_0, 8, 2000000); // Max 14 Mhz

    /* Enable the automatic hardware slave select function. Select the SS pin and configure as low-active. */
    //SPI_EnableAutoSS(SPI0, SPI_SS, SPI_SS_ACTIVE_HIGH);
		SPI_DisableAutoSS(SPI0);
		SPI_SET_LSB_FIRST(SPI0);	
		SPI_ENABLE(SPI0);
	
}

void QEI0_Init(void)
{
	/* Set QEI counting mode as X2 Free Counting Mode,
	set maximum counter value and enable IDX, QEA and QEB input */
	QEI_Open(QEI0, QEI_CTL_X2_COMPARE_COUNTING_MODE, 0x20);
	
//	QEI_ENABLE_INDEX_LATCH(QEI0);
	
	/* Start QEI function */
	QEI_Start(QEI0);	
}

void QEI0_Init_Index(uint32_t index)
{
	/* Set QEI counting mode as X2 Free Counting Mode,
	set maximum counter value and enable IDX, QEA and QEB input */
	QEI_Open(QEI0, QEI_CTL_X2_COMPARE_COUNTING_MODE, index);
	
	//QEI_ENABLE_INDEX_LATCH(QEI0);
	
	QEI_ENABLE_NOISE_FILTER(QEI0, QEI_CTL_NFCLKSEL_DIV64);
	
	/* Start QEI function */
	QEI_Start(QEI0);	
	
	QEI_ENABLE_INDEX_RELOAD(QEI0);
	
}


void TMR1_IRQHandler(void)
{
	if(TIMER_GetIntFlag(TIMER1) == 1)
	{
		/* Clear Timer1 time-out interrupt flag */
		TIMER_ClearIntFlag(TIMER1);
		usec++;
		vcom_sec++;
		if(vcom_sec >= (1000000 / EXTCOMIN_FREQ))
		{
			extcom_toggle();
			vcom_sec = 0;
		}
	}
}

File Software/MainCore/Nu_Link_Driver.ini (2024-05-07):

[Version]
Nu_LinkVersion=V5.9
[Process]
ProcessID=0x00003680
ProcessCreationTime_L=0xca830ff4
ProcessCreationTime_H=0x01da9e34
NuLinkID=0x1800022b
DisableFirmwareUpdate=0
NuLinkIDs_Count=0x00000001
NuLinkID0=0x1800022b
[ChipSelect]
;ChipName=<NUC1xx|NUC2xx|M05x|N571|N572|Nano100|N512|Mini51|NUC505|General>
ChipName=M481
[NUC505]
Connect=0
Reset=Autodetect
MaxClock=1MHz
MemoryVerify=0
IOVoltage=3300
Erase=1
Program=1
Verify=1
ResetAndRun=0
EnableFlashBreakpoint=0
EnableLog=0
MemAccessWhileRun=0
RAMForAlgorithmStart=0x20000000
RAMForAlgorithmSize=0x4000
ProgramAlgorithm=NUC505_SPIFLASH.FLM
[NUC4xx]
Connect=0
Reset=Autodetect
MaxClock=1MHz
MemoryVerify=0
IOVoltage=3300
FlashSelect=APROM
Erase=1
Program=1
Verify=1
ResetAndRun=0
EnableFlashBreakpoint=1
EnableLog=0
MemAccessWhileRun=0
RAMForAlgorithmStart=0x20000000
RAMForAlgorithmSize=0x4000
ProgramAlgorithm=NUC400_AP_512.FLM
TraceConf0=0x00000002
TraceConf1=0x014fb180
TraceConf2=0x00000800
TraceConf3=0x00000000
TraceConf4=0x00000001
TraceConf5=0x00000000
[NUC2xx]
Connect=0
Reset=Autodetect
MaxClock=1MHz
MemoryVerify=0
IOVoltage=3300
FlashSelect=APROM
Erase=1
Program=1
Verify=1
ResetAndRun=0
EnableFlashBreakpoint=1
EnableLog=0
MemAccessWhileRun=0
RAMForAlgorithmStart=0x20000000
RAMForAlgorithmSize=0x1000
ProgramAlgorithm=NUC200_AP_128.FLM
[NUC1311]
Connect=0
Reset=Autodetect
MaxClock=1MHz
MemoryVerify=0
IOVoltage=3300
FlashSelect=APROM
Erase=1
Program=1
Verify=1
ResetAndRun=0
EnableFlashBreakpoint=1
EnableLog=0
MemAccessWhileRun=0
RAMForAlgorithmStart=0x20000000
RAMForAlgorithmSize=0x1000
ProgramAlgorithm=NUC1311_AP_64.FLM
[NUC126]
Connect=0
Reset=Autodetect
MaxClock=1MHz
MemoryVerify=0
IOVoltage=3300
FlashSelect=APROM
Erase=1
Program=1
Verify=1
ResetAndRun=0
EnableFlashBreakpoint=1
EnableLog=0
MemAccessWhileRun=0
RAMForAlgorithmStart=0x20000000
RAMForAlgorithmSize=0x2000
ProgramAlgorithm=NUC126_AP_256.FLM
[NUC121]
Connect=0
Reset=Autodetect
MaxClock=1MHz
MemoryVerify=0
IOVoltage=3300
FlashSelect=APROM
Erase=1
Program=1
Verify=1
ResetAndRun=0
EnableFlashBreakpoint=1
EnableLog=0
MemAccessWhileRun=0
RAMForAlgorithmStart=0x20000000
RAMForAlgorithmSize=0x1000
ProgramAlgorithm=NUC121_AP_32.FLM
[NUC1xx]
Connect=0
Reset=Autodetect
MaxClock=1MHz
MemoryVerify=0
IOVoltage=3300
FlashSelect=APROM
Erase=1
Program=1
Verify=1
ResetAndRun=0
EnableFlashBreakpoint=1
EnableLog=0
MemAccessWhileRun=0
RAMForAlgorithmStart=0x20000000
RAMForAlgorithmSize=0x1000
ProgramAlgorithm=NUC100_AP_128.FLM
[NUC029]
Connect=0
Reset=Autodetect
MaxClock=1MHz
MemoryVerify=0
IOVoltage=3300
FlashSelect=APROM
Erase=1
Program=1
Verify=1
ResetAndRun=0
EnableFlashBreakpoint=1
EnableLog=0
MemAccessWhileRun=0
RAMForAlgorithmStart=0x20000000
RAMForAlgorithmSize=0x800
ProgramAlgorithm=NUC029_AP_16.FLM
[NM1820]
Connect=0
Reset=Autodetect
MaxClock=1MHz
MemoryVerify=0
IOVoltage=3300
FlashSelect=APROM
Erase=1
Program=1
Verify=1
ResetAndRun=0
EnableFlashBreakpoint=1
EnableLog=0
MemAccessWhileRun=0
RAMForAlgorithmStart=0x20000000
RAMForAlgorithmSize=0x800
ProgramAlgorithm=NM1820_AP_17_5.FLM
[NM1810]
Connect=0
Reset=Autodetect
MaxClock=1MHz
MemoryVerify=0
IOVoltage=3300
FlashSelect=APROM
Erase=1
Program=1
Verify=1
ResetAndRun=0
EnableFlashBreakpoint=1
EnableLog=0
MemAccessWhileRun=0
RAMForAlgorithmStart=0x20000000
RAMForAlgorithmSize=0x800
ProgramAlgorithm=NM1810_AP_29_5.FLM
[NM1500]
Connect=0
Reset=Autodetect
MaxClock=1MHz
MemoryVerify=0
IOVoltage=3300
FlashSelect=APROM
Erase=1
Program=1
Verify=1
ResetAndRun=0
EnableFlashBreakpoint=1
EnableLog=0
MemAccessWhileRun=0
RAMForAlgorithmStart=0x20000000
RAMForAlgorithmSize=0x1000
ProgramAlgorithm=NM1500_AP_128.FLM
[NM1330]
Connect=0
Reset=Autodetect
MaxClock=1MHz
MemoryVerify=0
IOVoltage=3300
FlashSelect=APROM
Erase=1
Program=1
Verify=1
ResetAndRun=0
EnableFlashBreakpoint=1
EnableLog=0
MemAccessWhileRun=0
RAMForAlgorithmStart=0x20000000
RAMForAlgorithmSize=0x1000
ProgramAlgorithm=NM1330_AP_64.FLM
[NM1320]
Connect=0
Reset=Autodetect
MaxClock=1MHz
MemoryVerify=0
IOVoltage=3300
FlashSelect=APROM
Erase=1
Program=1
Verify=1
ResetAndRun=0
EnableFlashBreakpoint=1
EnableLog=0
MemAccessWhileRun=0
RAMForAlgorithmStart=0x20000000
RAMForAlgorithmSize=0x1000
ProgramAlgorithm=NM1320_AP_32.FLM
[NM1240]
Connect=0
Reset=Autodetect
MaxClock=1MHz
MemoryVerify=0
IOVoltage=3300
FlashSelect=APROM
Erase=1
Program=1
Verify=1
ResetAndRun=0
EnableFlashBreakpoint=1
EnableLog=0
MemAccessWhileRun=0
RAMForAlgorithmStart=0x20000000
RAMForAlgorithmSize=0x1000
ProgramAlgorithm=NM1240_AP_64.FLM
[NM1230]
Connect=0
Reset=Autodetect
MaxClock=1MHz
MemoryVerify=0
IOVoltage=3300
FlashSelect=APROM
Erase=1
Program=1
Verify=1
ResetAndRun=0
EnableFlashBreakpoint=1
EnableLog=0
MemAccessWhileRun=0
RAMForAlgorithmStart=0x20000000
RAMForAlgorithmSize=0x1000
ProgramAlgorithm=NM1230_AP_64.FLM
[NM1200]
Connect=0
Reset=Autodetect
MaxClock=1MHz
MemoryVerify=0
IOVoltage=3300
FlashSelect=APROM
Erase=1
Program=1
Verify=1
ResetAndRun=0
EnableFlashBreakpoint=1
EnableLog=0
MemAccessWhileRun=0
RAMForAlgorithmStart=0x20000000
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

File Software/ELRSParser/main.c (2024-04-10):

#include <stdlib.h>
#include <stdio.h>
#include <string.h>
#include "main.h"

const char data[] = {
0xEA,	  // Destination
0x21, 	// Len
0x2B, 	// Frame Type
0xEA, 	// extended packet dest
0xEE, 	// extended packet src
0x03, 	// Config field index
0x00, 	// Chunk
0x00, 	// Parent
0x09, 	// Field Type
0x42, 0x54, 0x20, 0x54, 0x65, 0x6C, 0x65, 0x6D, 0x65, 0x74, 0x72, 0x79, 0x00, // BT Telemetry
0x4F, 0x66, 0x66, 0x3B, 0x4F, 0x6E, 0x00, // Off;On
0x00, 	// Field Value
0x00, 	// Minimum Value
0x01, 	// Maximum Value
0x00, 	// Default Value
0x00, 	// Unit
0x4C	// CRC
};

typedef struct {
    char label[256];
    char options[256];
    char *name;
    int type;
    int value;
    int minValue;
    int maxValue;
    char units[256];
} MenuItem;

MenuItem menu;


char recv_param_buffer[CRSF_MAX_CHUNKS * CRSF_MAX_CHUNK_SIZE];
char *recv_param_ptr;
u8 next_param;
u8 next_chunk;
u8 device_idx = 12;
u8 chunk;
u8 params_loaded = 0;
u8 update = 0;
crsf_param_t crsf_params[CRSF_MAX_PARAMS];


static void crsfdevice_init() {
    next_param = 1;
    next_chunk = 0;
    recv_param_ptr = recv_param_buffer;
    memset(crsf_params, 0, sizeof(crsf_params));
}

u32 millis()
{
  return 1000;
}


void parse_bytes(enum data_type type, char **buffer, char *dest)
{
  switch (type)
  {
  case UINT8:
    *(u8 *)dest = (u8)(*buffer)[0];
    *buffer += 1;
    break;
  case INT8:
    *(s8 *)dest = (s8)(*buffer)[0];
    *buffer += 1;
    break;
  case UINT16:
    *(u16 *)dest = (u16)(((*buffer)[0] << 8) | (*buffer)[1]);
    *buffer += 2;
    break;
  case INT16:
    *(s16 *)dest = (s16)(((*buffer)[0] << 8) | (*buffer)[1]);
    *buffer += 2;
    break;
  case FLOAT:
    *(s32 *)dest = (s32)(((*buffer)[0] << 24) | ((*buffer)[1] << 16) | ((*buffer)[2] << 8) | (*buffer)[3]);
    *buffer += 4;
    break;
  default:
    break;
  }
}

void add_param(u8 *buffer, u8 num_bytes)
{

    char *param_values;

    memcpy(recv_param_ptr, buffer+5, num_bytes-5);
    recv_param_ptr += num_bytes - 5;

    recv_param_ptr = recv_param_buffer;

    u8 param_id = buffer[5];

    crsf_params[param_id].device = 0;
    crsf_params[param_id].id = *recv_param_ptr++;
    crsf_params[param_id].parent = *recv_param_ptr++;
    crsf_params[param_id].chunk = *recv_param_ptr++;
    crsf_params[param_id].type = *recv_param_ptr & 0x7f;

    update = crsf_params[param_id].id == param_id;

    if(!update)
    {
      crsf_params[param_id].hidden = *recv_param_ptr++ & 0x80;
      crsf_params[param_id].name = (char *)malloc(strlen(recv_param_ptr) + 1);
      strncpy(crsf_params[param_id].name, (const char *)recv_param_ptr, strlen(recv_param_ptr) + 1);
      recv_param_ptr += strlen(recv_param_ptr) + 1;
    }
    else
    {
      if (crsf_params[param_id].hidden != (*recv_param_ptr & 0x80))
            params_loaded = 0;   // if item becomes hidden others may also, so reload all params
        crsf_params[param_id].hidden = *recv_param_ptr++ & 0x80;
        recv_param_ptr += strlen(recv_param_ptr) + 1;
    }

    

    u8 count;

    switch(crsf_params[param_id].type)
    {

       case UINT8:
       case INT8:
       case UINT16:
       case INT16:
       case FLOAT:
        parse_bytes(crsf_params[param_id].type, &recv_param_ptr, (char *)&crsf_params[param_id].value);
        parse_bytes(crsf_params[param_id].type, &recv_param_ptr, (char *)&crsf_params[param_id].min_value);
        parse_bytes(crsf_params[param_id].type, &recv_param_ptr, (char *)&crsf_params[param_id].max_value);
        parse_bytes(crsf_params[param_id].type, &recv_param_ptr, (char *)&crsf_params[param_id].default_value);
        if (crsf_params[param_id].type == FLOAT) {
            parse_bytes(UINT8, &recv_param_ptr, (char *)&crsf_params[param_id].u.point);
            parse_bytes(FLOAT, &recv_param_ptr, (char *)&crsf_params[param_id].step);
        } else if (*recv_param_ptr) {
            const u8 length = strlen(recv_param_ptr) + 1;
            if (!update) crsf_params[param_id].s.unit = malloc(length);
            strncpy(crsf_params[param_id].s.unit, (const char *)recv_param_ptr, length);
        }
       break;
       case TEXT_SELECTION:
            param_values = (char *)malloc(strlen(recv_param_ptr) + 1);
            strncpy(param_values, (const char *)recv_param_ptr, strlen(recv_param_ptr) + 1);
            recv_param_ptr += strlen(recv_param_ptr) + 1;
             // put null between selection options
            // find max choice string length to adjust textselectplate size
            char *start = (char *)param_values;
            count = 0;
            for (char *p = (char *)param_values; *p; p++)
            {
                if (*p == ';')
                {
                    u8 len = (strlen(start) - strlen(p));
                    crsf_params[param_id].options[count] = (char *)malloc(len + 1);
                    strncpy(crsf_params[param_id].options[count], start, len + 1);
                    crsf_params[param_id].options[count][len] = '\0';

                    start = p + 1;
                    count += 1;
                }
            }

            int len = strlen(start);
            crsf_params[param_id].options[count] = (char *)malloc(len + 1);
            strncpy(crsf_params[param_id].options[count], start, len + 1);

            // free(start);

            crsf_params[param_id].count = count;

            buffer = &buffer[buffer[1] - 4];

            parse_bytes(UINT8,  (char *)&buffer, (char *)&crsf_params[param_id].status);
            parse_bytes(UINT8,  (char *)&buffer, (char *)&crsf_params[param_id].min_value);
            parse_bytes(UINT8,  (char *)&buffer, (char *)&crsf_params[param_id].max_value); // don't use incorrect parameter->max_value
            parse_bytes(UINT8,  (char *)&buffer, (char *)&crsf_params[param_id].default_value);
        break;

        case INFO:
        if (!update) 
        {
            const u8 length = strlen(recv_param_ptr) + 1;
            crsf_params[param_id].value = malloc(length);
            strncpy(crsf_params[param_id].value, (const char *)recv_param_ptr, length);
        }

        case STRING:
        {
            const char *value;
            value = recv_param_ptr;
            recv_param_ptr += strlen(value) + 1;
            parse_bytes(UINT8, &recv_param_ptr, &crsf_params[param_id].u.string_max_len);

            // No string re-sizing so allocate max length for value
            if (!update)crsf_params[param_id].value = malloc(crsf_params[param_id].u.string_max_len+1);
            strncpy(crsf_params[param_id].value, value, crsf_params[param_id].u.string_max_len+1);
        }

        case COMMAND:
          parse_bytes(UINT8, &recv_param_ptr, (char *)&crsf_params[param_id].u.status);
          parse_bytes(UINT8, &recv_param_ptr, (char *)&crsf_params[param_id].timeout);
          if (!update) crsf_params[param_id].s.info = malloc(40);
          strncpy(crsf_params[param_id].s.info, (const char *)recv_param_ptr, 40);
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

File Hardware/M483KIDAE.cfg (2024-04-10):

/****************************************************************************
 * @file     M483KIDAE.cfg
 * @version  V1.24
 * @Date     2023/11/18-14:33:14 
 * @brief    NuMicro config file
 *
 * @note Please do not modify this file.
 *       Otherwise, it may not be loaded successfully.
 *
 * SPDX-License-Identifier: Apache-2.0
 *
 * Copyright (C) 2013-2023 Nuvoton Technology Corp. All rights reserved.
*****************************************************************************/
MCU:M483KIDAE(LQFP128)
Pin1:EADC0_CH5
Pin2:EADC0_CH4
Pin3:EADC0_CH3
Pin4:EADC0_CH2
Pin5:UART0_TXD
Pin6:UART0_RXD
Pin7:PC.10
Pin8:PC.9
Pin9:I2C1_SCL
Pin10:I2C1_SDA
Pin11:VSS
Pin12:VDD
Pin13:PA.11
Pin14:TM1_EXT
Pin15:UART1_TXD
Pin16:UART1_RXD
Pin17:BPWM0_CH4
Pin18:CLKO
Pin19:PD.11
Pin20:PD.10
Pin21:PG.2
Pin22:PG.3
Pin23:PG.4
Pin24:PF.11
Pin25:PF.10
Pin26:SPI0_SS
Pin27:SPI0_CLK
Pin28:PF.7
Pin29:SPI0_MOSI
Pin30:VDD
Pin31:X32_IN
Pin32:X32_OUT
Pin33:PH.4
Pin34:PH.5
Pin35:PH.6
Pin36:PH.7
Pin37:XT1_IN
Pin38:XT1_OUT
Pin39:VSS
Pin40:VDD
Pin41:PE.8
Pin42:PE.9
Pin43:PE.10
Pin44:PE.11
Pin45:PE.12
Pin46:PE.13
Pin47:PC.8
Pin48:PC.7
Pin49:PC.6
Pin50:PA.7
Pin51:PA.6
Pin52:VSS
Pin53:VDD
Pin54:LDO_CAP
Pin55:QEI0_INDEX
Pin56:QEI0_A
Pin57:QEI0_B
Pin58:PA.2
Pin59:PA.1
Pin60:UART1_nRTS
Pin61:VDDIO
Pin62:PE.14
Pin63:PE.15
Pin64:nRESET
Pin65:ICE_DAT
Pin66:ICE_CLK
Pin67:PD.9
Pin68:PD.8
Pin69:PC.5
Pin70:PC.4
Pin71:PC.3
Pin72:PC.2
Pin73:PC.1
Pin74:PC.0
Pin75:VSS
Pin76:VDD
Pin77:PG.9
Pin78:PG.10
Pin79:PG.11
Pin80:PG.12
Pin81:PG.13
Pin82:PG.14
Pin83:PG.15
Pin84:PD.13
Pin85:PA.12
Pin86:PA.13
Pin87:PA.14
Pin88:PA.15
Pin89:HSUSB_VRES
Pin90:HSUSB_VDD33
Pin91:HSUSB_VBUS
Pin92:HSUSB_D-
Pin93:HSUSB_VSS
Pin94:HSUSB_D+
Pin95:HSUSB_VDD12_CAP
Pin96:HSUSB_ID
Pin97:SD0_CMD
Pin98:SD0_CLK
Pin99:SD0_DAT3
Pin100:SD0_DAT2
Pin101:SD0_DAT1
Pin102:SD0_DAT0
Pin103:VSS
Pin104:VDD
Pin105:PE.1
Pin106:PE.0
Pin107:PH.8
Pin108:PH.9
Pin109:PH.10
Pin110:PH.11
Pin111:PD.14
Pin112:VSS
Pin113:LDO_CAP
Pin114:VDD
Pin115:PC.14
Pin116:PB.15
Pin117:PB.14
Pin118:DAC1_OUT
Pin119:SD0_nCD
Pin120:AVDD
Pin121:VREF
Pin122:AVSS
Pin123:EADC0_CH11
Pin124:EADC0_CH10
Pin125:EADC0_CH9
Pin126:EADC0_CH8
Pin127:EADC0_CH7
Pin128:EADC0_CH6
GPIOpin:57
GPIOpin:58
GPIOpin:33
GPIOpin:32
GPIOpin:34
GPIOpin:35
GPIOpin:116
GPIOpin:106
GPIOpin:107
GPIOpin:108
GPIOpin:48
GPIOpin:47
GPIOpin:46
GPIOpin:71
GPIOpin:70
GPIOpin:69
GPIOpin:68
GPIOpin:72
GPIOpin:6
GPIOpin:23
GPIOpin:24
GPIOpin:40
GPIOpin:41
GPIOpin:42
GPIOpin:43
GPIOpin:44
GPIOpin:45
GPIOpin:62
GPIOpin:61
SYS->GPA_MFPH = 0x00000D77
SYS->GPA_MFPL = 0x00EEE008
SYS->GPB_MFPH = 0x00191111
SYS->GPB_MFPL = 0x11111199
SYS->GPC_MFPH = 0x00933000
SYS->GPC_MFPL = 0x00000000
SYS->GPD_MFPH = 0x000D0000
SYS->GPE_MFPH = 0x00000000
SYS->GPE_MFPL = 0x33333300
SYS->GPF_MFPH = 0x00000055
SYS->GPF_MFPL = 0x05AAAAEE
SYS->GPG_MFPH = 0x00000000
SYS->GPG_MFPL = 0x00000000
SYS->GPH_MFPH = 0x00000000
SYS->GPH_MFPL = 0x00000000
/*** (C) COPYRIGHT 2013-2023 Nuvoton Technology Corp. ***/
